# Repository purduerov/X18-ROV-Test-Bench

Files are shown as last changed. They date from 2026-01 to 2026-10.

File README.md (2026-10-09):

# X18 ROV Test Bench

Surface test-bench hardware for the Purdue ROV team (X18 vehicle generation):
carrier and power boards for topside validation without the vehicle in the water.

## Layout

- `MCU and Pi Board/` — MCU + Raspberry Pi carrier board
  (`mcu and pi board.kicad_sch` / `.kicad_pcb`, project-local `Libraries/`,
  `custom library.*`)
- `power/` — power distribution board (`power.kicad_sch` / `.kicad_pcb`,
  `power_symbols.*`, rail sheets such as `12-5`, `48-12`, `STM`)

## Tooling

- Designed in KiCad — open the `.kicad_pro` in each board folder.
- Fab/plot outputs (`outputs/`, `manufacturing/`, Gerbers), KiCad
  auto-backups (`*-backups/`), caches, and component source archives
  (`*.zip`) are git-ignored; regenerate them locally.

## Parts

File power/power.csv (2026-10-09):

Reference | Value | MPN | LCSC | Qty | Footprint | DNP
C19,C27 | 0.1uF | CC0603KRX7R9BB104 | C14663 | 2 | Capacitor_SMD:C_0603_1608Metric
R4 | 73k2 | 0603WAF7322T5E | C14890 | 1 | Resistor_SMD:R_0603_1608Metric
C25,C28,C29 | 1uF | CL10A105KB8NNNC | C15849 | 3 | Capacitor_SMD:C_0603_1608Metric
R12,R13 | 0R | 0603WAF0000T5E | C21189 | 2 | Resistor_SMD:R_0603_1608Metric
R20,R21,R22 | 120R | 0603WAF1200T5E | C22787 | 3 | Resistor_SMD:R_0603_1608Metric
R17 | 15k | 0603WAF1502T5E | C22809 | 1 | Resistor_SMD:R_0603_1608Metric
R14 | 30k | 0603WAF3002T5E | C22984 | 1 | Resistor_SMD:R_0603_1608Metric
R8 | 52k3 | 0603WAF5232T5E | C23198 | 1 | Resistor_SMD:R_0603_1608Metric
R5 | 100k | 0603WAF1003T5E | C25803 | 1 | Resistor_SMD:R_0603_1608Metric
R1,R2,R3,R6,R7,R9,R10,R11,R15,R16 | 10k | 0603WAF1002T5E | C25804 | 10 | Resistor_SMD:R_0603_1608Metric
C13,C14,C15,C16,C17,C18,C23,C24,C30,C31,C33,C34 | 10uF | CL10A106MA8NRNC | C96446 | 12 | Capacitor_SMD:C_0603_1608Metric
C26 | 22nF 1mOhm | CC0603KRX7R9BB223 | C106222 | 1 | Capacitor_SMD:C_0603_1608Metric
C20 | 150pF 0Ohm | CC0603JRNPO9BN151 | C107038 | 1 | Capacitor_SMD:C_0603_1608Metric
C3,C4,C5 | 100uF 63V poly | RXW101M1JBK-0815 | C134638 | 3 | Capacitor_THT:CP_Radial_D8.0mm_P3.50mm
C11,C12 | 2.2mF 16V poly | GR1J222MM300A00CV0 | C240374 | 2 | Capacitor_THT:CP_Radial_D18.0mm_P7.50mm
C1,C2 | 330uF 63V poly | 63YXJ330M12.5X20 | C437640 | 2 | Capacitor_THT:CP_Radial_D12.5mm_P5.00mm
R18,R19,R23,R24,R25 | 680R 1/4W | ERJPA3J681V | C445820 | 5 | Resistor_SMD:R_0603_1608Metric
SW1 | SW_Push | TS04-66-70-BK-160-SMT | C455109 | 1 | power_symbols:TS04-66-70-BK-160-SMT
D2,D5 | RED | XL-1608SURC-06 | C965799 | 2 | LED_SMD:LED_0603_1608Metric
D3,D6 | GREEN | XL-1608UGC-04 | C965804 | 2 | LED_SMD:LED_0603_1608Metric
D1 | BLUE | XL-1608UBC-04 | C965807 | 1 | LED_SMD:LED_0603_1608Metric
C21,C22 | 22uF 2.582mOhm | CL10A226MO7JZNC | C2762594 | 2 | Capacitor_SMD:C_0603_1608Metric
C32 | 3u3 | TCC0603X5R335M250CT | C5360803 | 1 | Capacitor_SMD:C_0603_1608Metric
D4 | PURPLE | XL-1608UVC-04 | C7371898 | 1 | LED_SMD:LED_0603_1608Metric
 |  |  |  |  |  | DNP

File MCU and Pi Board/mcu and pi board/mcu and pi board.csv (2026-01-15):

Reference | Qty | Value | Voltage Rating | Footprint | Datasheet
C1,C5 | 2 | 47u | 10V | Capacitor_SMD:C_0805_2012Metric_Pad1.18x1.45mm_HandSolder | ~
C2,C3,C4,C7,C13,C14,C15,C16,C17,C18,C19 | 11 | 0.1u | 10V | Capacitor_SMD:C_0603_1608Metric_Pad1.08x0.95mm_HandSolder | ~
C6 | 1 | 10u | 10V | Capacitor_SMD:C_0805_2012Metric_Pad1.18x1.45mm_HandSolder | ~
C8,C22,C28,C29,C30,C31,C34,C36,C40 | 9 | 10u | 25V | Capacitor_SMD:C_0805_2012Metric_Pad1.18x1.45mm_HandSolder | ~
C9,C21,C32,C35,C37,C39 | 6 | 0.1u | 25V | Capacitor_SMD:C_0603_1608Metric_Pad1.08x0.95mm_HandSolder | ~
C10 | 1 | 0.47u | 10V | Capacitor_SMD:C_0603_1608Metric_Pad1.08x0.95mm_HandSolder | ~
C11 | 1 | 33u | 10V | Capacitor_SMD:C_0805_2012Metric_Pad1.18x1.45mm_HandSolder | ~
C12 | 1 | 10u | 10V | Capacitor_SMD:C_0603_1608Metric_Pad1.08x0.95mm_HandSolder | ~
C20 | 1 | 3.3n | 25V | Capacitor_SMD:C_0805_2012Metric_Pad1.18x1.45mm_HandSolder | ~
C23 | 1 | 0.1u | 16V | Capacitor_SMD:C_0603_1608Metric_Pad1.08x0.95mm_HandSolder | ~
C24 | 1 | 120p | 50V | Capacitor_SMD:C_0603_1608Metric_Pad1.08x0.95mm_HandSolder | ~
C25 | 1 | 4.7n | 50V | Capacitor_SMD:C_0805_2012Metric_Pad1.18x1.45mm_HandSolder | ~
C26 | 1 | 2.2u | 10V | Capacitor_SMD:C_0603_1608Metric_Pad1.08x0.95mm_HandSolder | ~
C27 | 1 | 1n | 50V | Capacitor_SMD:C_0603_1608Metric_Pad1.08x0.95mm_HandSolder | ~
C33 | 1 | 1u | 25V | Capacitor_SMD:C_0603_1608Metric_Pad1.08x0.95mm_HandSolder | ~
C38 | 1 | 100u | 10V | Capacitor_SMD:C_1206_3216Metric_Pad1.33x1.80mm_HandSolder | ~
D1 | 1 | GREEN_LED |  | LED_SMD:LED_0201_0603Metric_Pad0.64x0.40mm_HandSolder | ~
D2 | 1 | PURPLE_LED |  | LED_SMD:LED_0201_0603Metric_Pad0.64x0.40mm_HandSolder | ~
D3 | 1 | RED_LED |  | LED_SMD:LED_0201_0603Metric_Pad0.64x0.40mm_HandSolder | ~
D4 | 1 | ORANGE_LED |  | LED_SMD:LED_0201_0603Metric_Pad0.64x0.40mm_HandSolder | ~
IC1,IC2 | 2 | CSD17578Q3A |  | custom library:TRANS_CSD18543Q3A
J1 | 1 | BM04B-GHS-TBT |  | custom library:CONN_BM04B-GHS-TBT_JST | BM04B-GHS-TBT
J2 | 1 | ET60S-D04-3-08-D04-X-R1-S |  | custom library:SAMTEC_ET60S-D04-3-08-D04-X-R1-S
J3,J5 | 2 | PJ-002A |  | custom library:CUI_PJ-002A
J4 | 1 | Conn_01x04_Socket |  | Connector_JST:JST_PH_S4B-PH-K_1x04_P2.00mm_Horizontal | ~
J6,J24 | 2 | IPBT-105-H1-T-D-GP |  | custom library:SAMTEC_IPBT-105-H1-T-D-GP
J7 | 1 | Conn_02x04_Counter_Clockwise |  | Connector_PinHeader_2.54mm:PinHeader_2x04_P2.54mm_Vertical | ~
J8,J12,J21 | 3 | Conn_01x02_Pin |  | Connector_PinHeader_2.54mm:PinHeader_1x02_P2.54mm_Vertical | ~
J9 | 1 | Conn_01x05 |  | Connector_PinSocket_2.54mm:PinSocket_1x05_P2.54mm_Vertical | ~
J10 | 1 | 430450428 |  | custom library:MOLEX_430450428
J11,J18,J20 | 3 | Conn_01x04_Pin |  | Connector_PinHeader_2.54mm:PinHeader_1x04_P2.54mm_Vertical | ~
J13,J19,J22 | 3 | Conn_01x03_Pin |  | Connector_PinHeader_2.54mm:PinHeader_1x03_P2.54mm_Vertical | ~
J14 | 1 | ET60T-D04-0-00-D04-X-R1-S |  | custom library:SAMTEC_ET60T-D04-0-00-D04-X-R1-S
J15,J16 | 2 | Conn_01x28_Socket |  | Connector_PinSocket_2.54mm:PinSocket_1x28_P2.54mm_Vertical | ~
J17 | 1 | Conn_01x02_Pin |  | Connector_PinSocket_2.54mm:PinSocket_1x02_P2.54mm_Vertical | ~
J23 | 1 | Conn_02x02_Pin |  | Connector_PinSocket_2.54mm:PinSocket_2x02_P2.54mm_Vertical | ~
J25 | 1 | Conn_02x09_Counter_Clockwise |  | Connector_PinHeader_2.54mm:PinHeader_2x09_P2.54mm_Vertical | ~
J26,J29 | 2 | Conn_01x03_Pin |  | Connector_PinSocket_2.54mm:PinSocket_1x03_P2.54mm_Vertical | ~
J27 | 1 | DebugnBoot |  | Connector_PinHeader_2.54mm:PinHeader_1x04_P2.54mm_Vertical | ~
J28 | 1 | UART-PINS |  | Connector_PinHeader_2.54mm:PinHeader_1x03_P2.54mm_Vertical | ~
J30 | 1 | PWM Connector |  | custom library:PWM, 12V, GND JST Connector
J31 | 1 | ESC ADAPTER - BACKPLANE |  | custom library:ESC Adapter - Backplane
J32,J33,J34 | 3 | TB006-508-03BE |  | custom library:CUI_TB006-508-03BE
L1 | 1 | 1u |  | custom library:IND_XAL6030-102MEC | ~
Q1,Q2 | 2 | BSC010N04LS6ATMA1 |  | custom library:TRANS_BSC010N04LS6ATMA1
R1 | 1 | 290 |  | Resistor_SMD:R_0603_1608Metric_Pad0.98x0.95mm_HandSolder | ~
R2 | 1 | 270 |  | Resistor_SMD:R_0603_1608Metric_Pad0.98x0.95mm_HandSolder | ~
R3 | 1 | 510 |  | Resistor_SMD:R_0603_1608Metric_Pad0.98x0.95mm_HandSolder | ~
R4,R5,R6,R7,R8,R12 | 6 | 10k |  | Resistor_SMD:R_0603_1608Metric_Pad0.98x0.95mm_HandSolder | ~
R9 | 1 | 1.1k |  | Resistor_SMD:R_0603_1608Metric_Pad0.98x0.95mm_HandSolder | ~
R10 | 1 | 2.2k |  | Resistor_SMD:R_0603_1608Metric_Pad0.98x0.95mm_HandSolder | ~
R11 | 1 | 100k |  | Resistor_SMD:R_0603_1608Metric_Pad0.98x0.95mm_HandSolder | ~
R13 | 1 | 5.11k |  | Resistor_SMD:R_0603_1608Metric_Pad0.98x0.95mm_HandSolder | ~
R14 | 1 | 243 |  | Resistor_SMD:R_0603_1608Metric_Pad0.98x0.95mm_HandSolder | ~
R15 | 1 | 100 |  | Resistor_SMD:R_0603_1608Metric_Pad0.98x0.95mm_HandSolder | ~
R16 | 1 | 200 |  | Resistor_SMD:R_0603_1608Metric_Pad0.98x0.95mm_HandSolder | ~
S1 | 1 | TS04-66-70-BK-160-SMT |  | custom library:SW_TS04-66-70-BK-160-SMT
TP1,TP2,TP3,TP4,TP5,TP6,TP7 | 7 | TestPoint |  | TestPoint:TestPoint_Pad_D4.0mm | ~
U1 | 1 | LTC4370CMS_PBF |  | custom library:MSOP-16_MS | https://www.analog.com/media/en/technical-documentation/data-sheets/4370f.pdf
U2 | 1 | LM3940IMPX-3.3/NOPB |  | custom library:MP04A | https://www.ti.com/lit/gpn/lm3940
U3 | 1 | STM32F091CCT6 |  | custom library:LQFP48-7x7mm | https://www.st.com/resource/en/datasheet/stm32f091cc.pdf
U4 | 1 | RASPBERRY_PI_4B_4GB |  | custom library:MODULE_RASPBERRY_PI_4B_4GB
U5,U6 | 2 | MC74HC157ADR2G |  | custom library:SOIC-16_ONS | MC74HC157ADR2G
U7 | 1 | TPS40305DRCR |  | custom library:DRC10_2P4X1P65 | https://www.ti.com/lit/gpn/tps40305

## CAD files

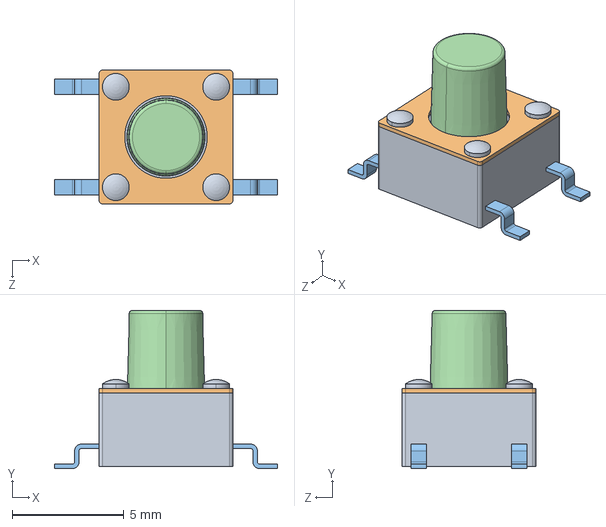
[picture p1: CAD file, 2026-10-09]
power/power_symbols.3d/TS04-66-70-BK-160-SMT.step
10.0 x 7.10 x 6.00 mm

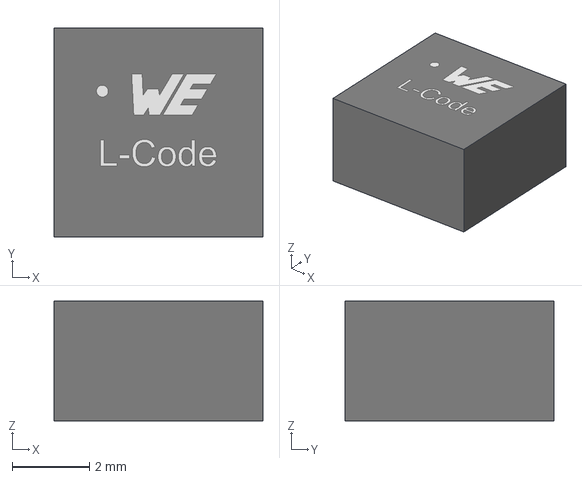
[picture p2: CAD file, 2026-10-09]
power/power_symbols.3d/WE-MXGI_5030.stp
5.40 x 5.40 x 3.10 mm
body_SSMC_5030
land_pattern x 2

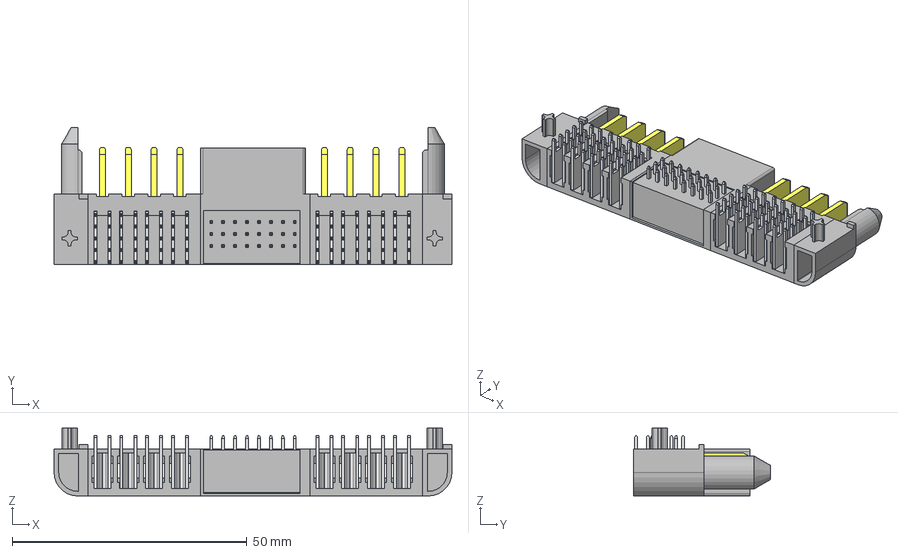
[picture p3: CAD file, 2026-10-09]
power/power_symbols.3d/ET60T-D04-3-08-D04-L-R1-S.stp
84.8 x 29.2 x 14.5 mm
ET60T-24-RT1-GP_st
ET60T-D-04-0-L-_POWER_TERMINAL
ET60T-RT1-GP_gpl
ET60T-D-04-R1-3_POWER_PINS_L_1
ET60T-D-042_POWER_PINS_2
ET60T-D-04-0-R-_POWER_TERMINAL
ET60T-RT1-GP_gpr
ET60T-D-04-R1-_POWER_PINS_R_1
ET60T-D-04-R1-2_POWER_PINS_R_2
ET60T-24-R1-_sp
ET60T-24-R1-2_sp

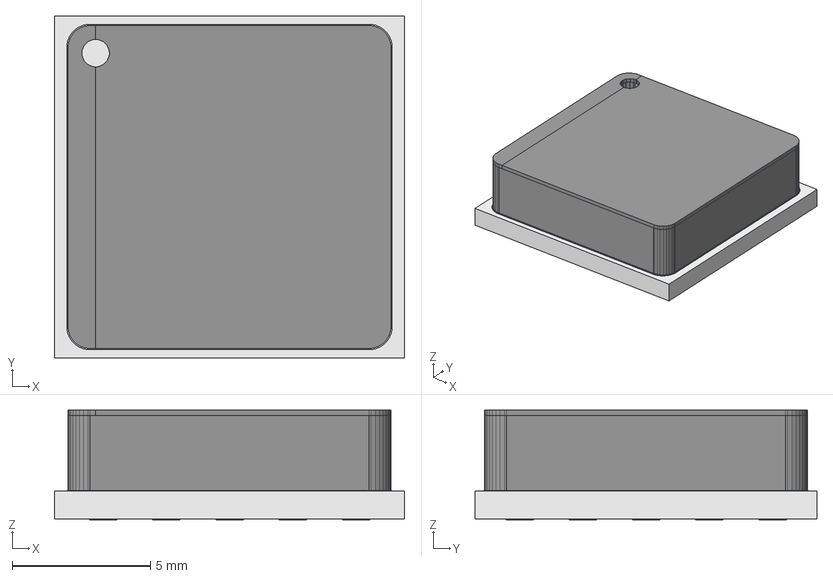
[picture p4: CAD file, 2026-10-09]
power/power_symbols.3d/RPM5.0-6.0.stp
12.7 x 12.4 x 3.97 mm
Extruded.step x 2
Extruded-0.step x 2
Extruded-1.step x 2
Extruded-2.step x 2
Extruded-3.step x 2
Extruded-4.step x 2
Extruded-5.step003 x 4
Extruded-6.step003 x 4
RPM_RBB_PCB028
RPM_RBB_PCB029
RPM_RBB_PCB030
RPM_RBB_PCB031
RPM_RBB_PCB032
RPM_RBB_PCB033
RPM_RBB_PCB034
RPM_RBB_PCB035
RPM_RBB_PCB036
RPM_RBB_PCB037
RPM_RBB_PCB038
RPM_RBB_PCB039
RPM_RBB_PCB040
RPM_RBB_PCB041
RPM_RBB_PCB042
RPM_RBB_PCB043
RPM_RBB_PCB044
RPM_RBB_PCB045
RPM_RBB_PCB046
RPM_RBB_PCB047
RPM_RBB_PCB048
RPM_RBB_PCB049
RPM_RBB_PCB050
RPM_RBB_PCB051
RPM_RBB_PCB052
RPM_RBB_PCB053
RPM_RBB_PCB054
RPM_RBB_PCB
RPM_RBB_PCB001
RPM_RBB_PCB002
RPM_RBB_PCB003
RPM_RBB_PCB004
RPM_RBB_PCB005
RPM_RBB_PCB006
RPM_RBB_PCB007
RPM_RBB_PCB008
RPM_RBB_PCB009
RPM_RBB_PCB010
RPM_RBB_PCB011
RPM_RBB_PCB012
RPM_RBB_PCB013
RPM_RBB_PCB014
RPM_RBB_PCB015
RPM_RBB_PCB016
RPM_RBB_PCB017
RPM_RBB_PCB018
RPM_RBB_PCB019
RPM_RBB_PCB020
RPM_RBB_PCB021
RPM_RBB_PCB022
RPM_RBB_PCB023
RPM_RBB_PCB024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

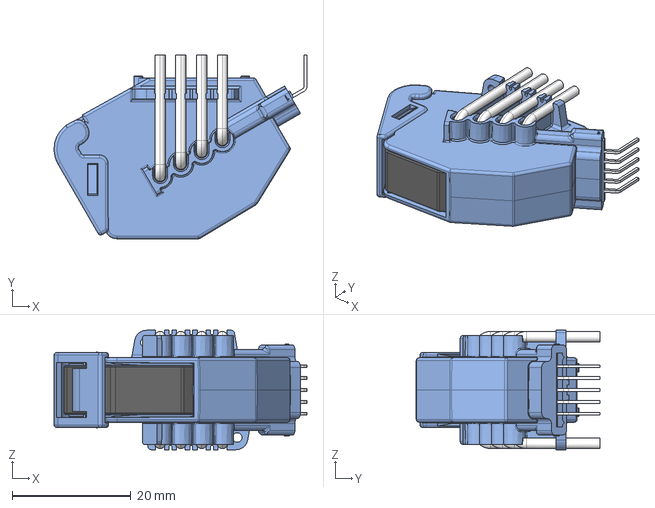
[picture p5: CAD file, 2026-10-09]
power/power_symbols.3d/HO-NP150.stp
42.6 x 30.9 x 20.1 mm

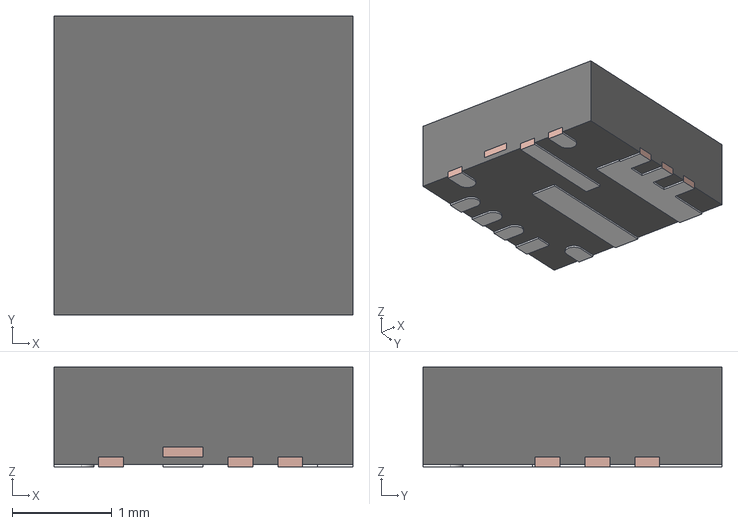
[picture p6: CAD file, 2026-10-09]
power/power_symbols.3d/TPS56A37RPAR.stp
3.00 x 3.00 x 1.00 mm
FRAME
MOLD

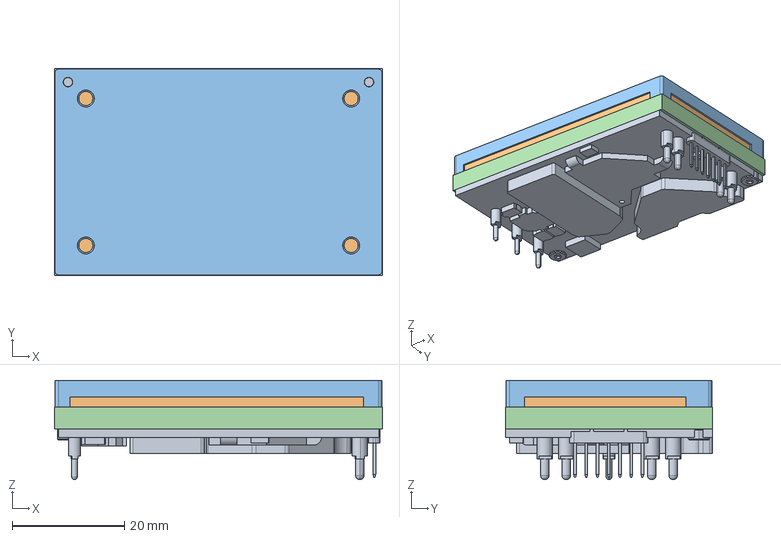
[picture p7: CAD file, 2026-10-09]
power/power_symbols.3d/bmr4912510_871.stp
58.4 x 36.8 x 17.7 mm

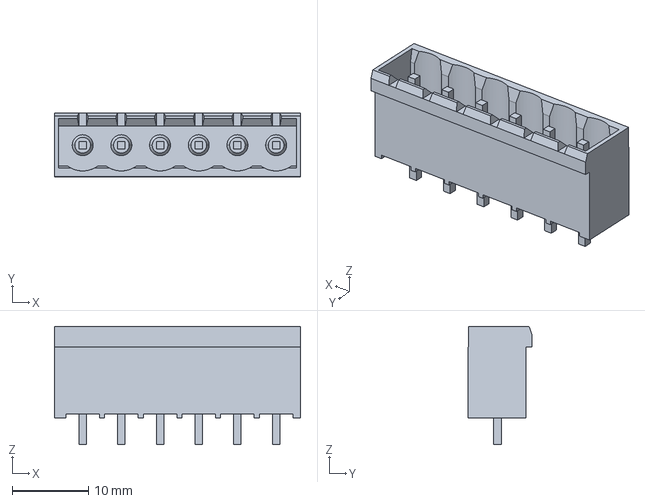
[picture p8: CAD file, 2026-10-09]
power/power_symbols.3d/796636-6.stp
32.3 x 8.35 x 15.5 mm

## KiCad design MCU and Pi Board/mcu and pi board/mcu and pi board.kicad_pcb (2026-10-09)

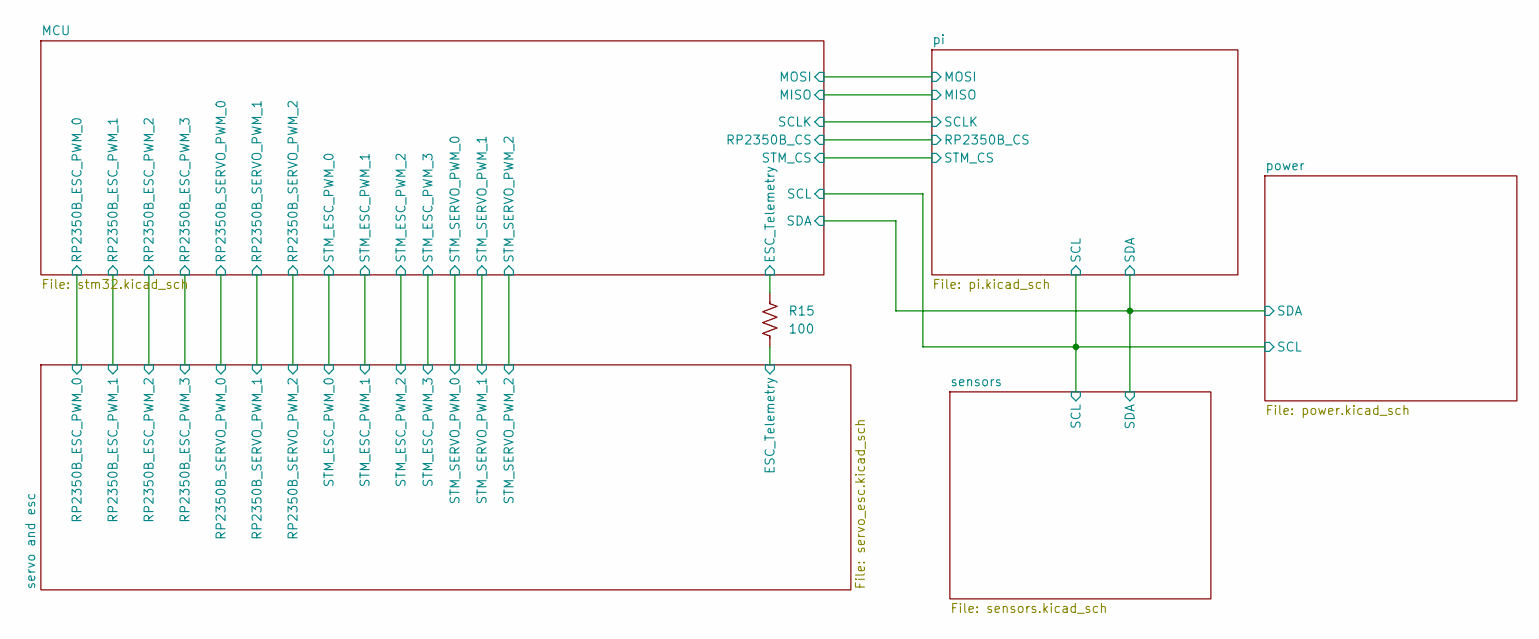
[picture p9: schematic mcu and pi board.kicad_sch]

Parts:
R15: 100; R_0603_1608Metric_Pad0.98x0.95mm_HandSolder

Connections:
/MCU/GPIO13: R15.1; also elsewhere on the board
/servo and esc/ESC_Telemetry: R15.2; also elsewhere on the board

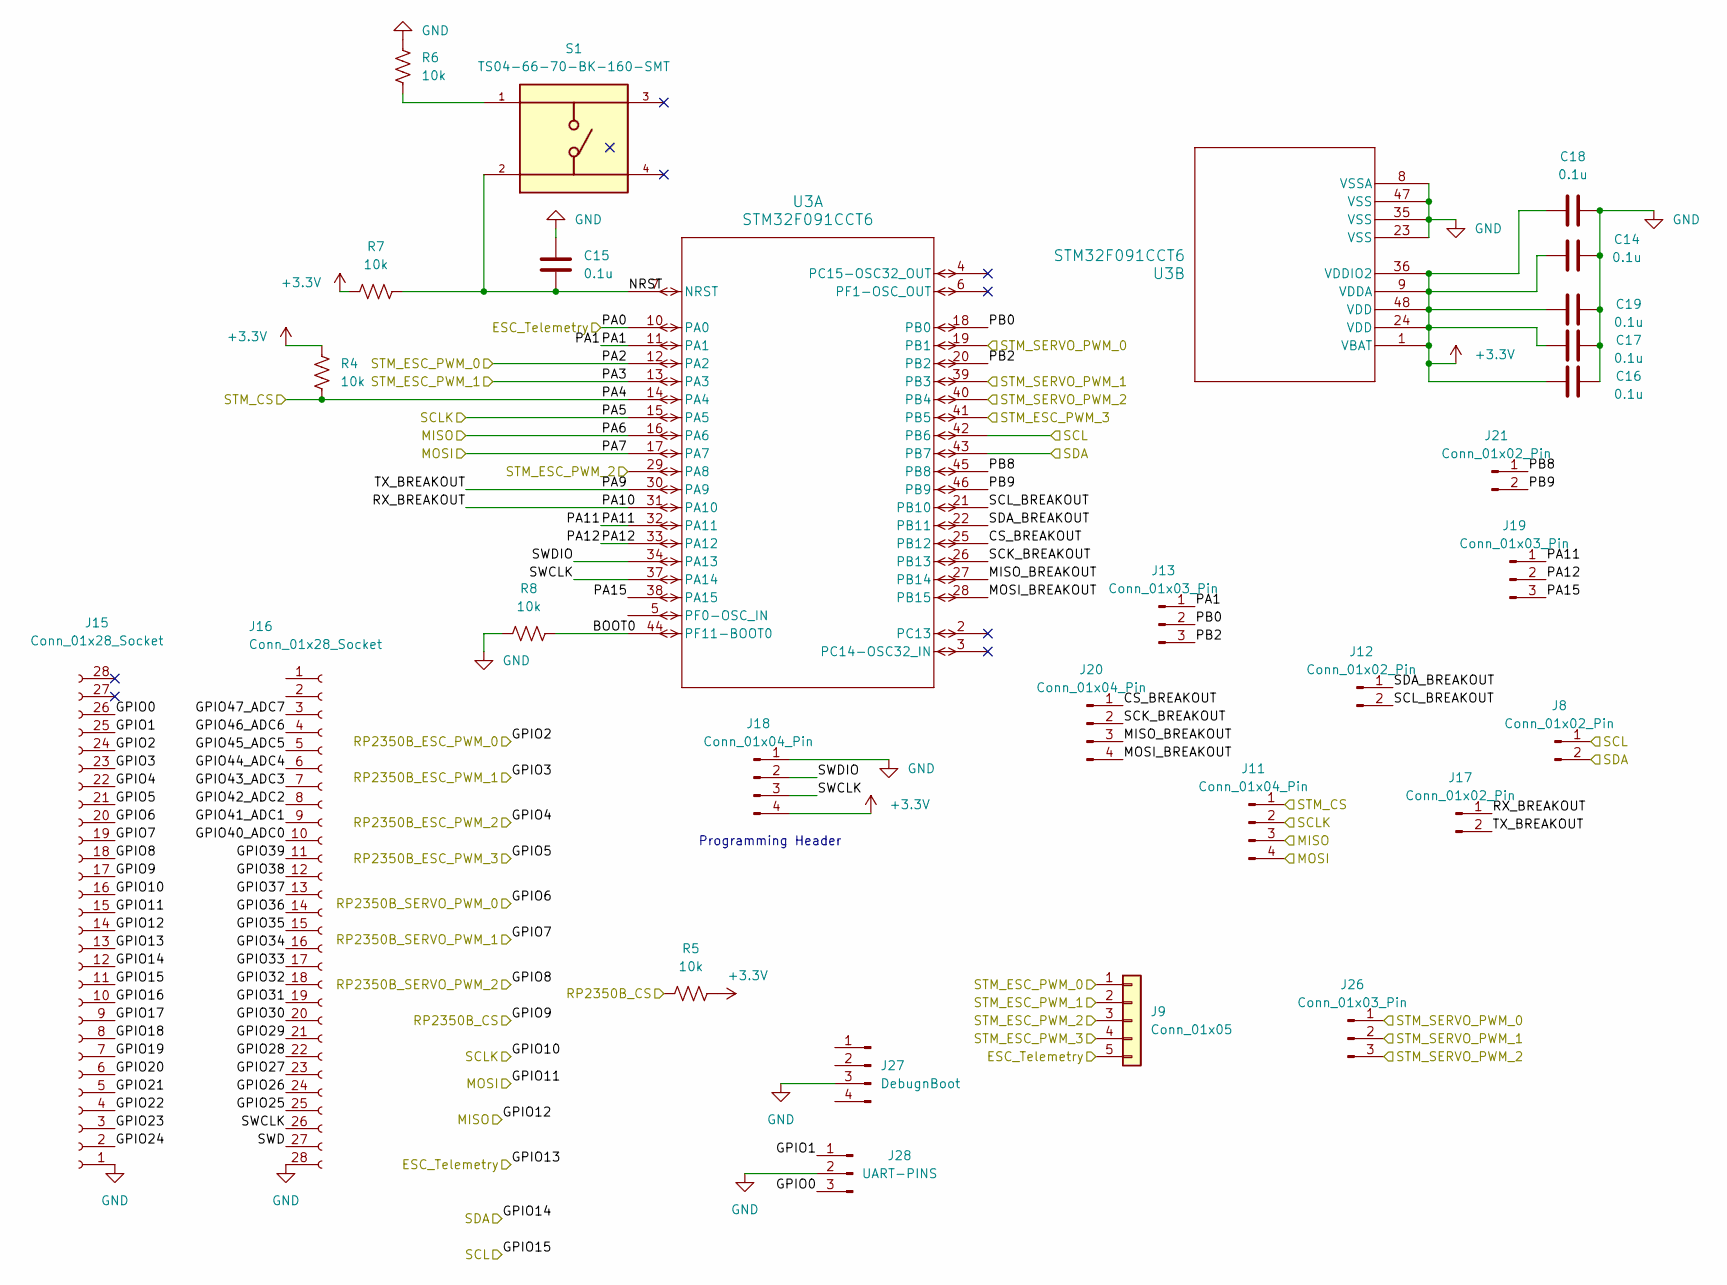
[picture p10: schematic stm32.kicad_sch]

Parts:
C14, C15, C16, C17, C18, C19: 0.1u; C_0603_1608Metric_Pad1.08x0.95mm_HandSolder; Voltage Rating 10V
J8, J12, J21: Conn_01x02_Pin; PinHeader_1x02_P2.54mm_Vertical
J9: Conn_01x05; PinSocket_1x05_P2.54mm_Vertical
J11, J18, J20: Conn_01x04_Pin; PinHeader_1x04_P2.54mm_Vertical
J13, J19: Conn_01x03_Pin; PinHeader_1x03_P2.54mm_Vertical
J15, J16: Conn_01x28_Socket; PinSocket_1x28_P2.54mm_Vertical
J17: Conn_01x02_Pin; PinSocket_1x02_P2.54mm_Vertical
J26: Conn_01x03_Pin; PinSocket_1x03_P2.54mm_Vertical
J27: DebugnBoot; PinHeader_1x04_P2.54mm_Vertical
J28: UART-PINS; PinHeader_1x03_P2.54mm_Vertical
R4, R5, R6, R7, R8: 10k; R_0603_1608Metric_Pad0.98x0.95mm_HandSolder
S1: TS04-66-70-BK-160-SMT; SW_TS04-66-70-BK-160-SMT; PARTREV 1.0
U3: STM32F091CCT6; LQFP48-7x7mm

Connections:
+3.3V: C14.1, C16.1, C17.1, C18.1, C19.1, J18.4, R4.1, R5.2, R7.1, U3.1 (VBAT), U3.9 (VDDA), U3.24 (VDD), U3.36 (VDDIO2), U3.48 (VDD); also elsewhere on the board
/MCU/BOOT0: R8.2, U3.44 (PF11-BOOT0)
/MCU/CS_BREAKOUT: J20.1, U3.25 (PB12)
/MCU/GPIO0: J15.26, J28.3
/MCU/GPIO1: J15.25, J28.1
/MCU/GPIO2: J15.24; also elsewhere on the board
/MCU/GPIO3: J15.23; also elsewhere on the board
/MCU/GPIO4: J15.22; also elsewhere on the board
/MCU/GPIO5: J15.21; also elsewhere on the board
/MCU/GPIO6: J15.20; also elsewhere on the board
/MCU/GPIO7: J15.19; also elsewhere on the board
/MCU/GPIO8: J15.18; also elsewhere on the board
/MCU/GPIO9: J15.17, R5.1; also elsewhere on the board
/MCU/GPIO10: J11.2, J15.16, U3.15 (PA5); also elsewhere on the board
/MCU/GPIO11: J11.4, J15.15, U3.17 (PA7); also elsewhere on the board
/MCU/GPIO12: J11.3, J15.14, U3.16 (PA6); also elsewhere on the board
/MCU/GPIO13: J9.5, J15.13, U3.10 (PA0); also elsewhere on the board
/MCU/GPIO14: J8.2, J15.12, U3.43 (PB7); also elsewhere on the board
/MCU/GPIO15: J8.1, J15.11, U3.42 (PB6); also elsewhere on the board
/MCU/GPIO16: J15.10
/MCU/GPIO17: J15.9
/MCU/GPIO18: J15.8
/MCU/GPIO19: J15.7
/MCU/GPIO20: J15.6
/MCU/GPIO21: J15.5
/MCU/GPIO22: J15.4
/MCU/GPIO23: J15.3
/MCU/GPIO24: J15.2
/MCU/GPIO25: J16.25
/MCU/GPIO26: J16.24
/MCU/GPIO27: J16.23
/MCU/GPIO28: J16.22
/MCU/GPIO29: J16.21
/MCU/GPIO30: J16.20
/MCU/GPIO31: J16.19
/MCU/GPIO32: J16.18
/MCU/GPIO33: J16.17
/MCU/GPIO34: J16.16
/MCU/GPIO35: J16.15
/MCU/GPIO36: J16.14
/MCU/GPIO37: J16.13
/MCU/GPIO38: J16.12
/MCU/GPIO39: J16.11
/MCU/GPIO40_ADC0: J16.10
/MCU/GPIO41_ADC1: J16.9
/MCU/GPIO42_ADC2: J16.8
/MCU/GPIO43_ADC3: J16.7
/MCU/GPIO44_ADC4: J16.6
/MCU/GPIO45_ADC5: J16.5
/MCU/GPIO46_ADC6: J16.4
/MCU/GPIO47_ADC7: J16.3
/MCU/MISO_BREAKOUT: J20.3, U3.27 (PB14)
/MCU/MOSI_BREAKOUT: J20.4, U3.28 (PB15)
/MCU/NRST: C15.2, R7.2, S1.2, U3.7 (NRST)
/MCU/PA1: J13.1, U3.11 (PA1)
/MCU/PA2: J9.1, U3.12 (PA2); also elsewhere on the board
/MCU/PA3: J9.2, U3.13 (PA3); also elsewhere on the board
/MCU/PA4: J11.1, R4.2, U3.14 (PA4); also elsewhere on the board
/MCU/PA9: J17.2, U3.30 (PA9)
/MCU/PA10: J17.1, U3.31 (PA10)
/MCU/PA11: J19.1, U3.32 (PA11)
/MCU/PA12: J19.2, U3.33 (PA12)
/MCU/PA15: J19.3, U3.38 (PA15)
/MCU/PB0: J13.2, U3.18 (PB0)
/MCU/PB2: J13.3, U3.20 (PB2)
/MCU/PB8: J21.1, U3.45 (PB8)
/MCU/PB9: J21.2, U3.46 (PB9)
/MCU/SCK_BREAKOUT: J20.2, U3.26 (PB13)
/MCU/SCL_BREAKOUT: J12.2, U3.21 (PB10)
/MCU/SDA_BREAKOUT: J12.1, U3.22 (PB11)
/MCU/STM_ESC_PWM_2: J9.3, U3.29 (PA8); also elsewhere on the board
/MCU/STM_ESC_PWM_3: J9.4, U3.41 (PB5); also elsewhere on the board
/MCU/STM_SERVO_PWM_0: J26.1, U3.19 (PB1); also elsewhere on the board
/MCU/STM_SERVO_PWM_1: J26.2, U3.39 (PB3); also elsewhere on the board
/MCU/STM_SERVO_PWM_2: J26.3, U3.40 (PB4); also elsewhere on the board
/MCU/SWCLK: J16.26
/MCU/SWCLK: J18.3, U3.37 (PA14)
/MCU/SWD: J16.27
/MCU/SWDIO: J18.2, U3.34 (PA13)
GND: C14.2, C15.1, C16.2, C17.2, C18.2, C19.2, J15.1, J16.28, J18.1, J27.3, J28.2, R6.2, R8.1, U3.8 (VSSA), U3.23 (VSS), U3.35 (VSS), U3.47 (VSS); also elsewhere on the board
unnamed: R6.1, S1.1

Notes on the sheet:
Programming Header

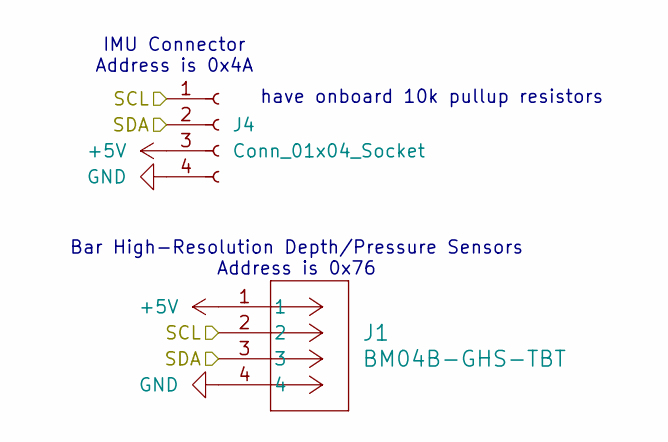
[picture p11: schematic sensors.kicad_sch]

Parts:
J1: BM04B-GHS-TBT; CONN_BM04B-GHS-TBT_JST
J4: Conn_01x04_Socket; JST_PH_S4B-PH-K_1x04_P2.00mm_Horizontal

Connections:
+5V: J1.1, J4.3; also elsewhere on the board
/MCU/GPIO14: J1.3, J4.2; also elsewhere on the board
/MCU/GPIO15: J1.2, J4.1; also elsewhere on the board
GND: J1.4, J4.4; also elsewhere on the board

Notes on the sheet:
Bar High-Resolution Depth/Pressure Sensors Address is 0x76
have onboard 10k pullup resistors
IMU Connector Address is 0x4A

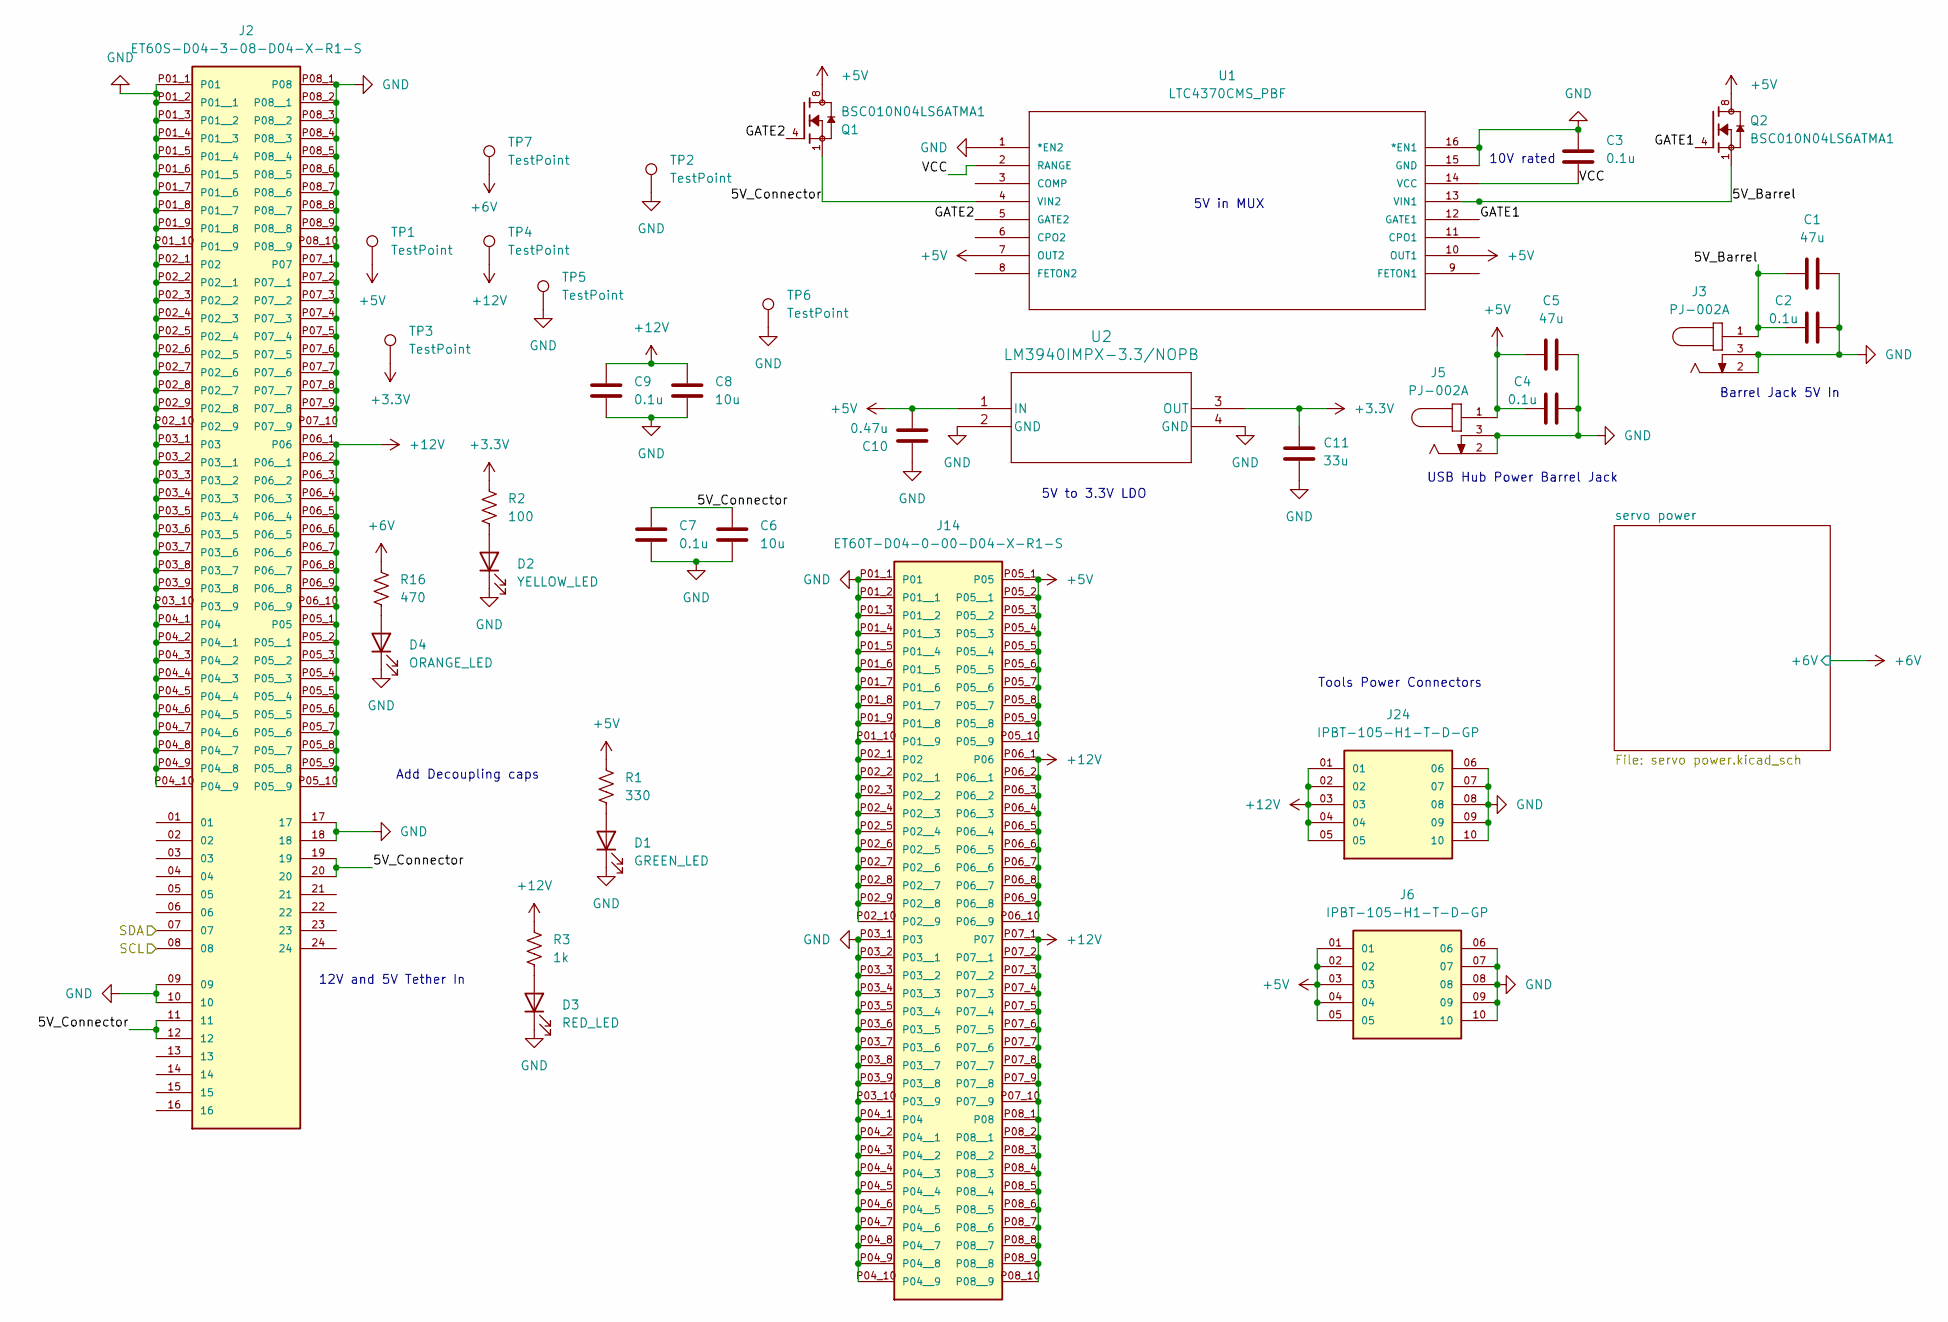
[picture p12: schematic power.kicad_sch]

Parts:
C1, C5: 47u; C_0805_2012Metric_Pad1.18x1.45mm_HandSolder; Voltage Rating 10V
C2, C3, C4, C7: 0.1u; C_0603_1608Metric_Pad1.08x0.95mm_HandSolder; Voltage Rating 10V
C6: 10u; C_0805_2012Metric_Pad1.18x1.45mm_HandSolder; Voltage Rating 10V
C8: 10u; C_0805_2012Metric_Pad1.18x1.45mm_HandSolder; Voltage Rating 25V
C9: 0.1u; C_0603_1608Metric_Pad1.08x0.95mm_HandSolder; Voltage Rating 25V
C10: 0.47u; C_0603_1608Metric_Pad1.08x0.95mm_HandSolder; Voltage Rating 10V
C11: 33u; C_0805_2012Metric_Pad1.18x1.45mm_HandSolder; Voltage Rating 10V
D1: GREEN_LED; LED_0805_2012Metric_Pad1.15x1.40mm_HandSolder
D2: YELLOW_LED; LED_0805_2012Metric_Pad1.15x1.40mm_HandSolder
D3: RED_LED; LED_0603_1608Metric_Pad1.05x0.95mm_HandSolder
D4: ORANGE_LED; LED_0603_1608Metric_Pad1.05x0.95mm_HandSolder
J2: ET60S-D04-3-08-D04-X-R1-S; SAMTEC_ET60S-D04-3-08-D04-X-R1-S; PARTREV G
J3, J5: PJ-002A; CUI_PJ-002A
J6, J24: IPBT-105-H1-T-D-GP; SAMTEC_IPBT-105-H1-T-D-GP; PARTREV R
J14: ET60T-D04-0-00-D04-X-R1-S; SAMTEC_ET60T-D04-0-00-D04-X-R1-S; PARTREV K
Q1, Q2: BSC010N04LS6ATMA1; TRANS_BSC010N04LS6ATMA1
R1: 330; R_0603_1608Metric_Pad0.98x0.95mm_HandSolder
R2: 100; R_0603_1608Metric_Pad0.98x0.95mm_HandSolder
R3: 1k; R_0603_1608Metric_Pad0.98x0.95mm_HandSolder
R16: 470; R_0603_1608Metric_Pad0.98x0.95mm_HandSolder
TP1, TP2, TP3, TP4, TP5, TP6, TP7: TestPoint; TestPoint_Pad_D4.0mm
U1: LTC4370CMS_PBF; MSOP-16_MS; MANUFACTURER_PART_NUMBER ltc4370cms#pbf
U2: LM3940IMPX-3.3/NOPB; MP04A

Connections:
+3.3V: C11.1, R2.1, TP3.1, U2.3 (OUT); also elsewhere on the board
+5V: C4.2, C5.1, C10.2, J5.1, J6.01, J6.02, J6.03, J6.04, J6.05, J14.P05_1 (P05), J14.P05_2 (P05__1), J14.P05_3 (P05__2), J14.P05_4 (P05__3), J14.P05_5 (P05__4), J14.P05_6 (P05__5), J14.P05_7 (P05__6), J14.P05_8 (P05__7), J14.P05_9 (P05__8), J14.P05_10 (P05__9), Q1.8, Q2.8, R1.1, TP1.1, U1.7 (OUT2), U1.10 (OUT1), U2.1 (IN); also elsewhere on the board
+6V: R16.1, TP7.1; also elsewhere on the board
+12V: C8.1, C9.1, J2.P05_1 (P05), J2.P05_2 (P05__1), J2.P05_3 (P05__2), J2.P05_4 (P05__3), J2.P05_5 (P05__4), J2.P05_6 (P05__5), J2.P05_7 (P05__6), J2.P05_8 (P05__7), J2.P05_9 (P05__8), J2.P05_10 (P05__9), J2.P06_1 (P06), J2.P06_2 (P06__1), J2.P06_3 (P06__2), J2.P06_4 (P06__3), J2.P06_5 (P06__4), J2.P06_6 (P06__5), J2.P06_7 (P06__6), J2.P06_8 (P06__7), J2.P06_9 (P06__8), J2.P06_10 (P06__9), J14.P06_1 (P06), J14.P06_2 (P06__1), J14.P06_3 (P06__2), J14.P06_4 (P06__3), J14.P06_5 (P06__4), J14.P06_6 (P06__5), J14.P06_7 (P06__6), J14.P06_8 (P06__7), J14.P06_9 (P06__8), J14.P06_10 (P06__9), J14.P07_1 (P07), J14.P07_2 (P07__1), J14.P07_3 (P07__2), J14.P07_4 (P07__3), J14.P07_5 (P07__4), J14.P07_6 (P07__5), J14.P07_7 (P07__6), J14.P07_8 (P07__7), J14.P07_9 (P07__8), J14.P07_10 (P07__9), J14.P08_1 (P08), J14.P08_2 (P08__1), J14.P08_3 (P08__2), J14.P08_4 (P08__3), J14.P08_5 (P08__4), J14.P08_6 (P08__5), J14.P08_7 (P08__6), J14.P08_8 (P08__7), J14.P08_9 (P08__8), J14.P08_10 (P08__9), J24.01, J24.02, J24.03, J24.04, J24.05, R3.1, TP4.1; also elsewhere on the board
/MCU/GPIO14: J2.07; also elsewhere on the board
/MCU/GPIO15: J2.08; also elsewhere on the board
/power/5V_Barrel: C1.1, C2.2, J3.1, Q2.1, U1.13 (VIN1)
/power/5V_Connector: C6.1, C7.1, J2.11, J2.12, J2.19, J2.20, Q1.1, U1.4 (VIN2)
/power/GATE1: Q2.4, U1.12 (GATE1)
/power/GATE2: Q1.4, U1.5 (GATE2)
/power/VCC: C3.2, U1.2 (RANGE), U1.14 (VCC)
GND: C1.2, C2.1, C3.1, C4.1, C5.2, C6.2, C7.2, C8.2, C9.2, C10.1, C11.2, D1.1 (K), D2.1 (K), D3.1 (K), D4.1 (K), J2.09, J2.10, J2.17, J2.18, J2.P01_1 (P01), J2.P01_2 (P01__1), J2.P01_3 (P01__2), J2.P01_4 (P01__3), J2.P01_5 (P01__4), J2.P01_6 (P01__5), J2.P01_7 (P01__6), J2.P01_8 (P01__7), J2.P01_9 (P01__8), J2.P01_10 (P01__9), J2.P02_1 (P02), J2.P02_2 (P02__1), J2.P02_3 (P02__2), J2.P02_4 (P02__3), J2.P02_5 (P02__4), J2.P02_6 (P02__5), J2.P02_7 (P02__6), J2.P02_8 (P02__7), J2.P02_9 (P02__8), J2.P02_10 (P02__9), J2.P03_1 (P03), J2.P03_2 (P03__1), J2.P03_3 (P03__2), J2.P03_4 (P03__3), J2.P03_5 (P03__4), J2.P03_6 (P03__5), J2.P03_7 (P03__6), J2.P03_8 (P03__7), J2.P03_9 (P03__8), J2.P03_10 (P03__9), J2.P04_1 (P04), J2.P04_2 (P04__1), J2.P04_3 (P04__2), J2.P04_4 (P04__3), J2.P04_5 (P04__4), J2.P04_6 (P04__5), J2.P04_7 (P04__6), J2.P04_8 (P04__7), J2.P04_9 (P04__8), J2.P04_10 (P04__9), J2.P07_1 (P07), J2.P07_2 (P07__1), J2.P07_3 (P07__2), J2.P07_4 (P07__3), J2.P07_5 (P07__4), J2.P07_6 (P07__5), J2.P07_7 (P07__6), J2.P07_8 (P07__7), J2.P07_9 (P07__8), J2.P07_10 (P07__9), J2.P08_1 (P08), J2.P08_2 (P08__1), J2.P08_3 (P08__2), J2.P08_4 (P08__3), J2.P08_5 (P08__4), J2.P08_6 (P08__5), J2.P08_7 (P08__6), J2.P08_8 (P08__7), J2.P08_9 (P08__8), J2.P08_10 (P08__9), J3.2, J3.3, J5.2, J5.3, J6.06, J6.07, J6.08, J6.09, J6.10, J14.P01_1 (P01), J14.P01_2 (P01__1), J14.P01_3 (P01__2), J14.P01_4 (P01__3), J14.P01_5 (P01__4), J14.P01_6 (P01__5), J14.P01_7 (P01__6), J14.P01_8 (P01__7), J14.P01_9 (P01__8), J14.P01_10 (P01__9), J14.P02_1 (P02), J14.P02_2 (P02__1), J14.P02_3 (P02__2), J14.P02_4 (P02__3), J14.P02_5 (P02__4), J14.P02_6 (P02__5), J14.P02_7 (P02__6), J14.P02_8 (P02__7), J14.P02_9 (P02__8), J14.P02_10 (P02__9), J14.P03_1 (P03), J14.P03_2 (P03__1), J14.P03_3 (P03__2), J14.P03_4 (P03__3), J14.P03_5 (P03__4), J14.P03_6 (P03__5), J14.P03_7 (P03__6), J14.P03_8 (P03__7), J14.P03_9 (P03__8), J14.P03_10 (P03__9), J14.P04_1 (P04), J14.P04_2 (P04__1), J14.P04_3 (P04__2), J14.P04_4 (P04__3), J14.P04_5 (P04__4), J14.P04_6 (P04__5), J14.P04_7 (P04__6), J14.P04_8 (P04__7), J14.P04_9 (P04__8), J14.P04_10 (P04__9), J24.06, J24.07, J24.08, J24.09, J24.10, TP2.1, TP5.1, TP6.1, U1.1 (*EN2), U1.15 (GND), U1.16 (*EN1), U2.2 (GND), U2.4 (GND); also elsewhere on the board
unnamed: D1.2 (A), R1.2
unnamed: D2.2 (A), R2.2
unnamed: D3.2 (A), R3.2
unnamed: D4.2 (A), R16.2

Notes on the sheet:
USB Hub Power Barrel Jack
Barrel Jack 5V In
12V and 5V Tether In
10V rated
Tools Power Connectors
Add Decoupling caps
5V to 3.3V LDO
5V in MUX

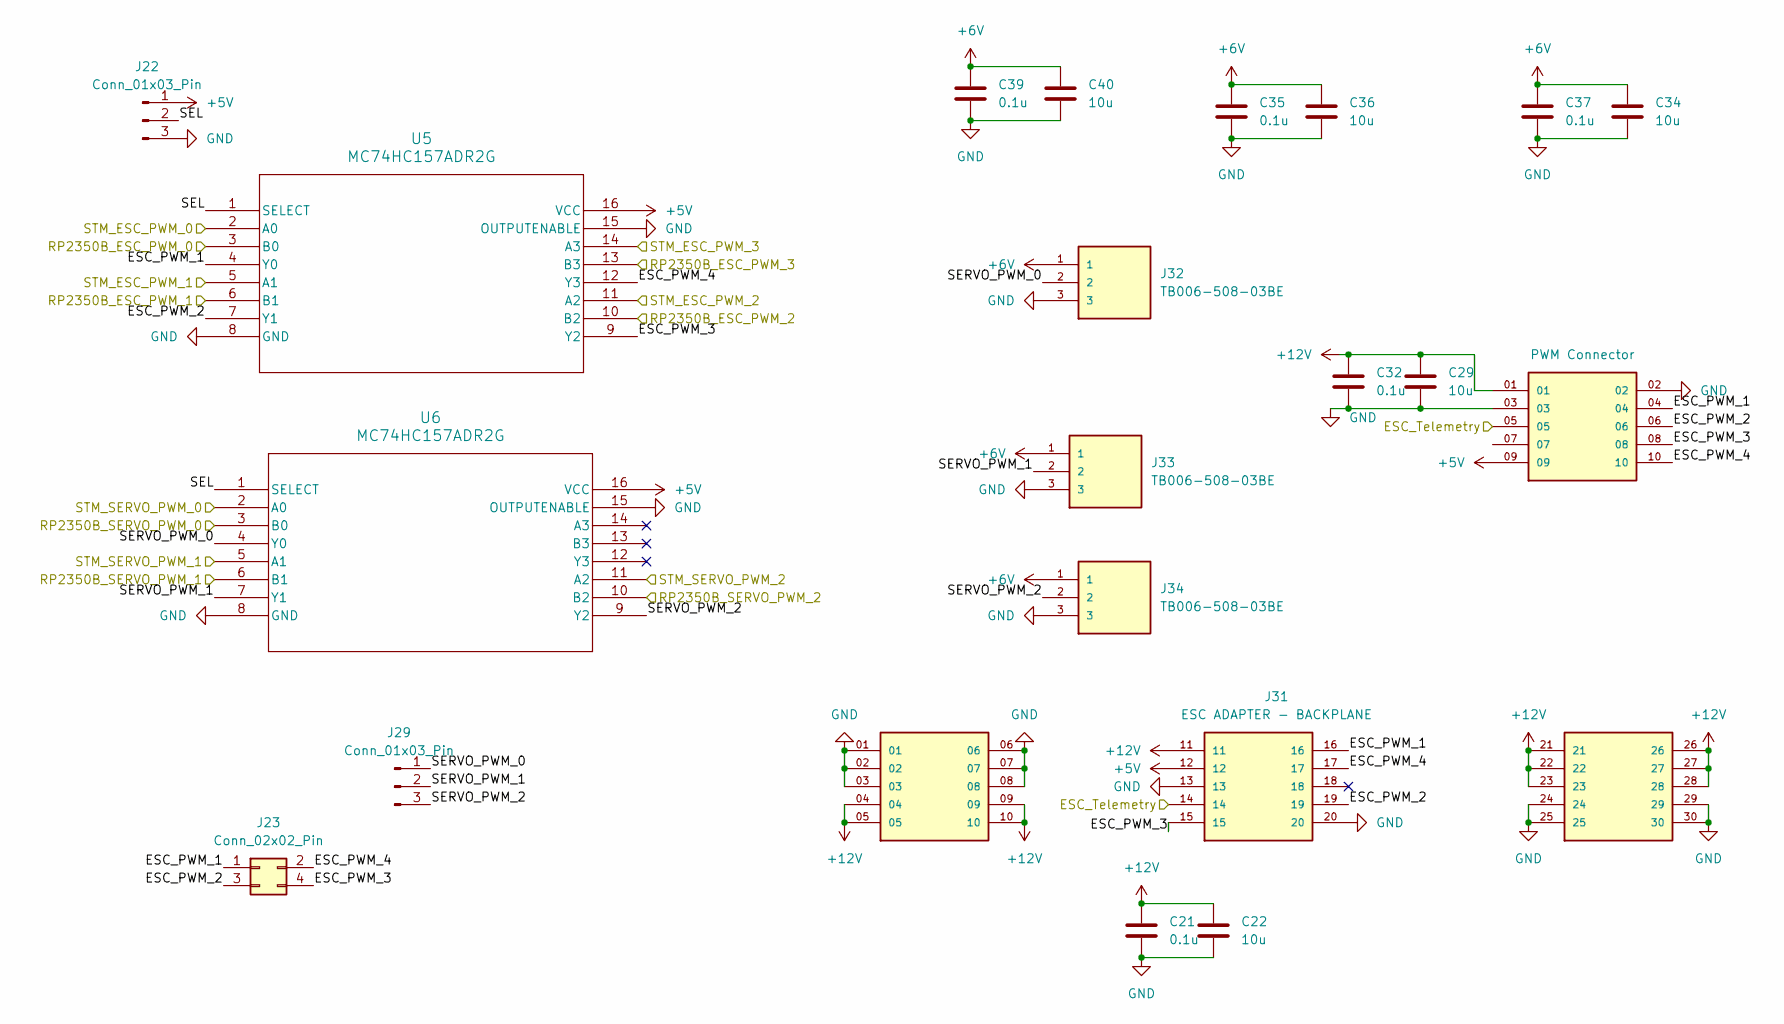
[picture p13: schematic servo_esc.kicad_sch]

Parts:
C21, C32, C35, C37, C39: 0.1u; C_0603_1608Metric_Pad1.08x0.95mm_HandSolder; Voltage Rating 25V
C22, C29, C34, C36, C40: 10u; C_0805_2012Metric_Pad1.18x1.45mm_HandSolder; Voltage Rating 25V
J22: Conn_01x03_Pin; PinHeader_1x03_P2.54mm_Vertical
J23: Conn_02x02_Pin; PinSocket_2x02_P2.54mm_Vertical
J29: Conn_01x03_Pin; PinSocket_1x03_P2.54mm_Vertical
J30: PWM Connector; PWM, 12V, GND JST Connector; PARTREV R
J31: ESC ADAPTER - BACKPLANE; ESC Adapter - Backplane; PARTREV R
J32, J33, J34: TB006-508-03BE; CUI_TB006-508-03BE
U5, U6: MC74HC157ADR2G; SOIC-16_ONS

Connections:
+5V: J22.1, J30.09, J31.12, U5.16 (VCC), U6.16 (VCC); also elsewhere on the board
+6V: C34.1, C35.1, C36.1, C37.1, C39.1, C40.1, J32.1, J33.1, J34.1; also elsewhere on the board
+12V: C21.1, C22.1, C29.1, C32.1, J30.01, J31.04, J31.05, J31.09, J31.10, J31.11, J31.21, J31.22, J31.23, J31.26, J31.27, J31.28; also elsewhere on the board
/MCU/GPIO2: U5.3 (B0); also elsewhere on the board
/MCU/GPIO3: U5.6 (B1); also elsewhere on the board
/MCU/GPIO4: U5.10 (B2); also elsewhere on the board
/MCU/GPIO5: U5.13 (B3); also elsewhere on the board
/MCU/GPIO6: U6.3 (B0); also elsewhere on the board
/MCU/GPIO7: U6.6 (B1); also elsewhere on the board
/MCU/GPIO8: U6.10 (B2); also elsewhere on the board
/MCU/PA2: U5.2 (A0); also elsewhere on the board
/MCU/PA3: U5.5 (A1); also elsewhere on the board
/MCU/STM_ESC_PWM_2: U5.11 (A2); also elsewhere on the board
/MCU/STM_ESC_PWM_3: U5.14 (A3); also elsewhere on the board
/MCU/STM_SERVO_PWM_0: U6.2 (A0); also elsewhere on the board
/MCU/STM_SERVO_PWM_1: U6.5 (A1); also elsewhere on the board
/MCU/STM_SERVO_PWM_2: U6.11 (A2); also elsewhere on the board
/servo and esc/ESC_PWM_1: J23.1, J30.04, J31.16, U5.4 (Y0)
/servo and esc/ESC_PWM_2: J23.3, J30.06, J31.19, U5.7 (Y1)
/servo and esc/ESC_PWM_3: J23.4, J30.08, J31.15, U5.9 (Y2)
/servo and esc/ESC_PWM_4: J23.2, J30.10, J31.17, U5.12 (Y3)
/servo and esc/ESC_Telemetry: J30.05, J31.14; also elsewhere on the board
/servo and esc/SEL: J22.2, U5.1 (SELECT), U6.1 (SELECT)
/servo and esc/SERVO_PWM_0: J29.1, J32.2, U6.4 (Y0)
/servo and esc/SERVO_PWM_1: J29.2, J33.2, U6.7 (Y1)
/servo and esc/SERVO_PWM_2: J29.3, J34.2, U6.9 (Y2)
GND: C21.2, C22.2, C29.2, C32.2, C34.2, C35.2, C36.2, C37.2, C39.2, C40.2, J22.3, J30.02, J30.03, J31.01, J31.02, J31.03, J31.06, J31.07, J31.08, J31.13, J31.20, J31.24, J31.25, J31.29, J31.30, J32.3, J33.3, J34.3, U5.8 (GND), U5.15 (OUTPUTENABLE), U6.8 (GND), U6.15 (OUTPUTENABLE); also elsewhere on the board

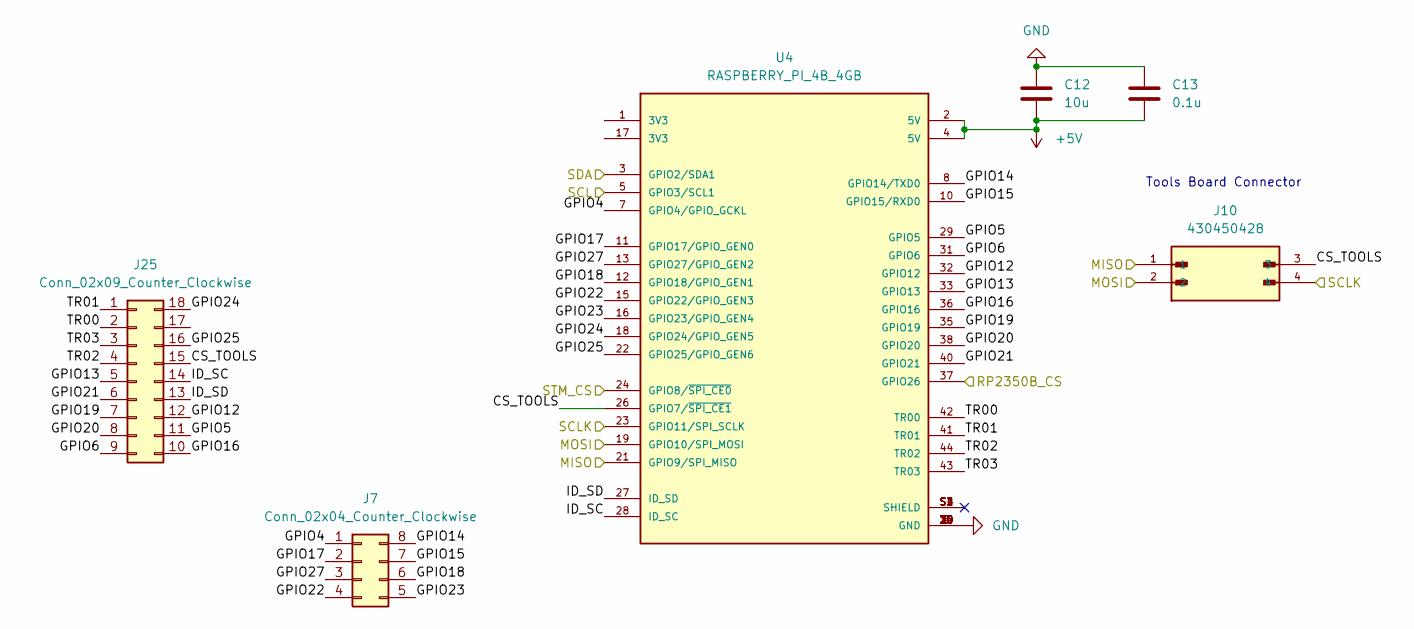
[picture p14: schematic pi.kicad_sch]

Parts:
C12: 10u; C_0603_1608Metric_Pad1.08x0.95mm_HandSolder; Voltage Rating 10V
C13: 0.1u; C_0603_1608Metric_Pad1.08x0.95mm_HandSolder; Voltage Rating 10V
J7: Conn_02x04_Counter_Clockwise; PinHeader_2x04_P2.54mm_Vertical
J10: 430450428; MOLEX_430450428; PARTREV G1
J25: Conn_02x09_Counter_Clockwise; PinHeader_2x09_P2.54mm_Vertical
U4: RASPBERRY_PI_4B_4GB; MODULE_RASPBERRY_PI_4B_4GB; PARTREV 4

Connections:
+5V: C12.2, C13.2, U4.2 (5V), U4.4 (5V); also elsewhere on the board
/MCU/GPIO9: U4.37 (GPIO26); also elsewhere on the board
/MCU/GPIO10: J10.4, U4.23 (GPIO11/SPI_SCLK); also elsewhere on the board
/MCU/GPIO11: J10.2, U4.19 (GPIO10/SPI_MOSI); also elsewhere on the board
/MCU/GPIO12: J10.1, U4.21 (GPIO9/SPI_MISO); also elsewhere on the board
/MCU/GPIO14: U4.3 (GPIO2/SDA1); also elsewhere on the board
/MCU/GPIO15: U4.5 (GPIO3/SCL1); also elsewhere on the board
/MCU/PA4: U4.24 (GPIO8/~SPI_CE0); also elsewhere on the board
/pi/CS_TOOLS: J10.3, J25.15, U4.26 (GPIO7/~SPI_CE1)
/pi/GPIO4: J7.1, U4.7 (GPIO4/GPIO_GCKL)
/pi/GPIO5: J25.11, U4.29 (GPIO5)
/pi/GPIO6: J25.9, U4.31 (GPIO6)
/pi/GPIO12: J25.12, U4.32 (GPIO12)
/pi/GPIO13: J25.5, U4.33 (GPIO13)
/pi/GPIO14: J7.8, U4.8 (GPIO14/TXD0)
/pi/GPIO15: J7.7, U4.10 (GPIO15/RXD0)
/pi/GPIO16: J25.10, U4.36 (GPIO16)
/pi/GPIO17: J7.2, U4.11 (GPIO17/GPIO_GEN0)
/pi/GPIO18: J7.6, U4.12 (GPIO18/GPIO_GEN1)
/pi/GPIO19: J25.7, U4.35 (GPIO19)
/pi/GPIO20: J25.8, U4.38 (GPIO20)
/pi/GPIO21: J25.6, U4.40 (GPIO21)
/pi/GPIO22: J7.4, U4.15 (GPIO22/GPIO_GEN3)
/pi/GPIO23: J7.5, U4.16 (GPIO23/GPIO_GEN4)
/pi/GPIO24: J25.18, U4.18 (GPIO24/GPIO_GEN5)
/pi/GPIO25: J25.16, U4.22 (GPIO25/GPIO_GEN6)
/pi/GPIO27: J7.3, U4.13 (GPIO27/GPIO_GEN2)
/pi/ID_SC: J25.14, U4.28 (ID_SC)
/pi/ID_SD: J25.13, U4.27 (ID_SD)
/pi/TR00: J25.2, U4.42 (TR00)
/pi/TR01: J25.1, U4.41 (TR01)
/pi/TR02: J25.4, U4.44 (TR02)
/pi/TR03: J25.3, U4.43 (TR03)
GND: C12.1, C13.1, U4.6 (GND), U4.9 (GND), U4.14 (GND), U4.20 (GND), U4.25 (GND), U4.30 (GND), U4.34 (GND), U4.39 (GND); also elsewhere on the board

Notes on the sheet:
Tools Board Connector

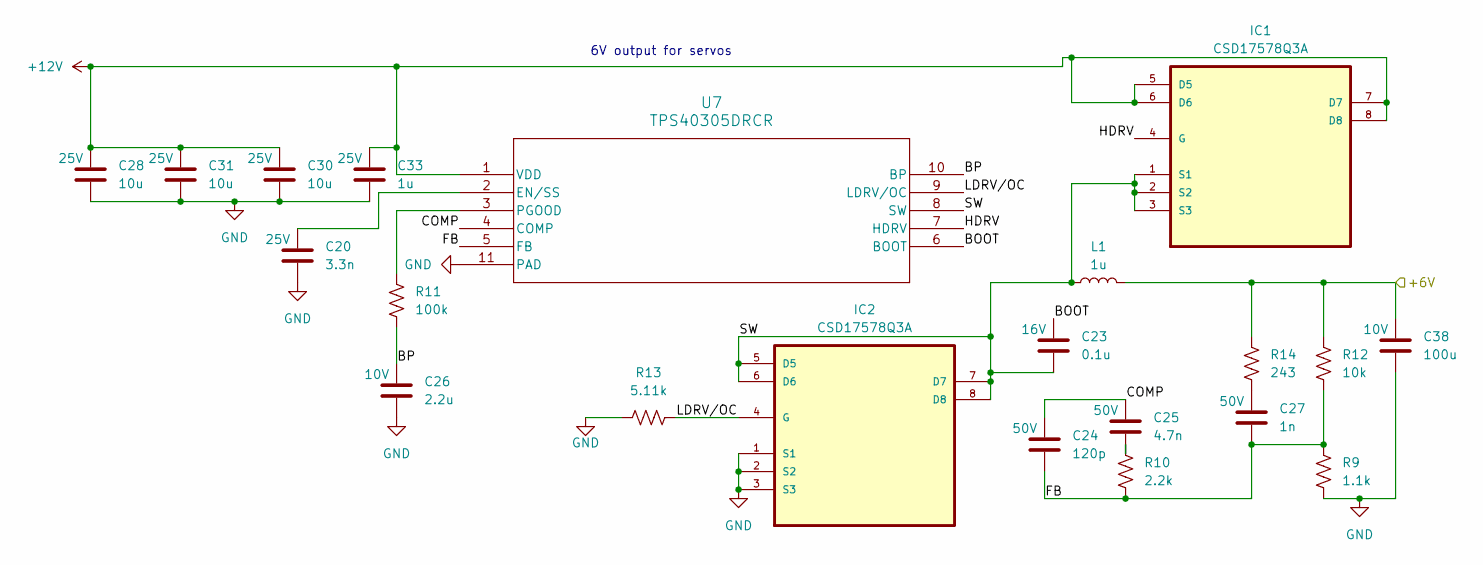
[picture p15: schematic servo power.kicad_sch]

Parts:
C20: 3.3n; C_0805_2012Metric_Pad1.18x1.45mm_HandSolder; Voltage Rating 25V
C23: 0.1u; C_0603_1608Metric_Pad1.08x0.95mm_HandSolder; Voltage Rating 16V
C24: 120p; C_0603_1608Metric_Pad1.08x0.95mm_HandSolder; Voltage Rating 50V
C25: 4.7n; C_0805_2012Metric_Pad1.18x1.45mm_HandSolder; Voltage Rating 50V
C26: 2.2u; C_0603_1608Metric_Pad1.08x0.95mm_HandSolder; Voltage Rating 10V
C27: 1n; C_0603_1608Metric_Pad1.08x0.95mm_HandSolder; Voltage Rating 50V
C28, C30, C31: 10u; C_0805_2012Metric_Pad1.18x1.45mm_HandSolder; Voltage Rating 25V
C33: 1u; C_0603_1608Metric_Pad1.08x0.95mm_HandSolder; Voltage Rating 25V
C38: 100u; C_1206_3216Metric_Pad1.33x1.80mm_HandSolder; Voltage Rating 10V
IC1, IC2: CSD17578Q3A; TRANS_CSD18543Q3A
L1: 1u; IND_XAL6030-102MEC
R9: 1.1k; R_0603_1608Metric_Pad0.98x0.95mm_HandSolder
R10: 2.2k; R_0603_1608Metric_Pad0.98x0.95mm_HandSolder
R11: 100k; R_0603_1608Metric_Pad0.98x0.95mm_HandSolder
R12: 10k; R_0603_1608Metric_Pad0.98x0.95mm_HandSolder
R13: 5.11k; R_0603_1608Metric_Pad0.98x0.95mm_HandSolder
R14: 243; R_0603_1608Metric_Pad0.98x0.95mm_HandSolder
U7: TPS40305DRCR; DRC10_2P4X1P65

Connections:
+6V: C38.1, L1.2, R12.1, R14.1; also elsewhere on the board
+12V: C28.1, C30.1, C31.1, C33.1, IC1.5 (D5), IC1.6 (D6), IC1.7 (D7), IC1.8 (D8), U7.1 (VDD); also elsewhere on the board
/power/servo power/BOOT: C23.1, U7.6 (BOOT)
/power/servo power/BP: C26.1, R11.2, U7.10 (BP)
/power/servo power/COMP: C24.1, C25.1, U7.4 (COMP)
/power/servo power/FB: C24.2, C27.2, R9.1, R10.2, R12.2, U7.5 (FB)
/power/servo power/HDRV: IC1.4 (G), U7.7 (HDRV)
/power/servo power/LDRV/OC: IC2.4 (G), R13.2, U7.9 (LDRV/OC)
/power/servo power/SW: C23.2, IC1.1 (S1), IC1.2 (S2), IC1.3 (S3), IC2.5 (D5), IC2.6 (D6), IC2.7 (D7), IC2.8 (D8), L1.1, U7.8 (SW)
GND: C20.2, C26.2, C28.2, C30.2, C31.2, C33.2, C38.2, IC2.1 (S1), IC2.2 (S2), IC2.3 (S3), R9.2, R13.1, U7.11 (PAD); also elsewhere on the board
unnamed: C25.2, R10.1
unnamed: C27.1, R14.2
unnamed: C20.1, U7.2 (EN/SS)
unnamed: R11.1, U7.3 (PGOOD)

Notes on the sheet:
6V output for servos

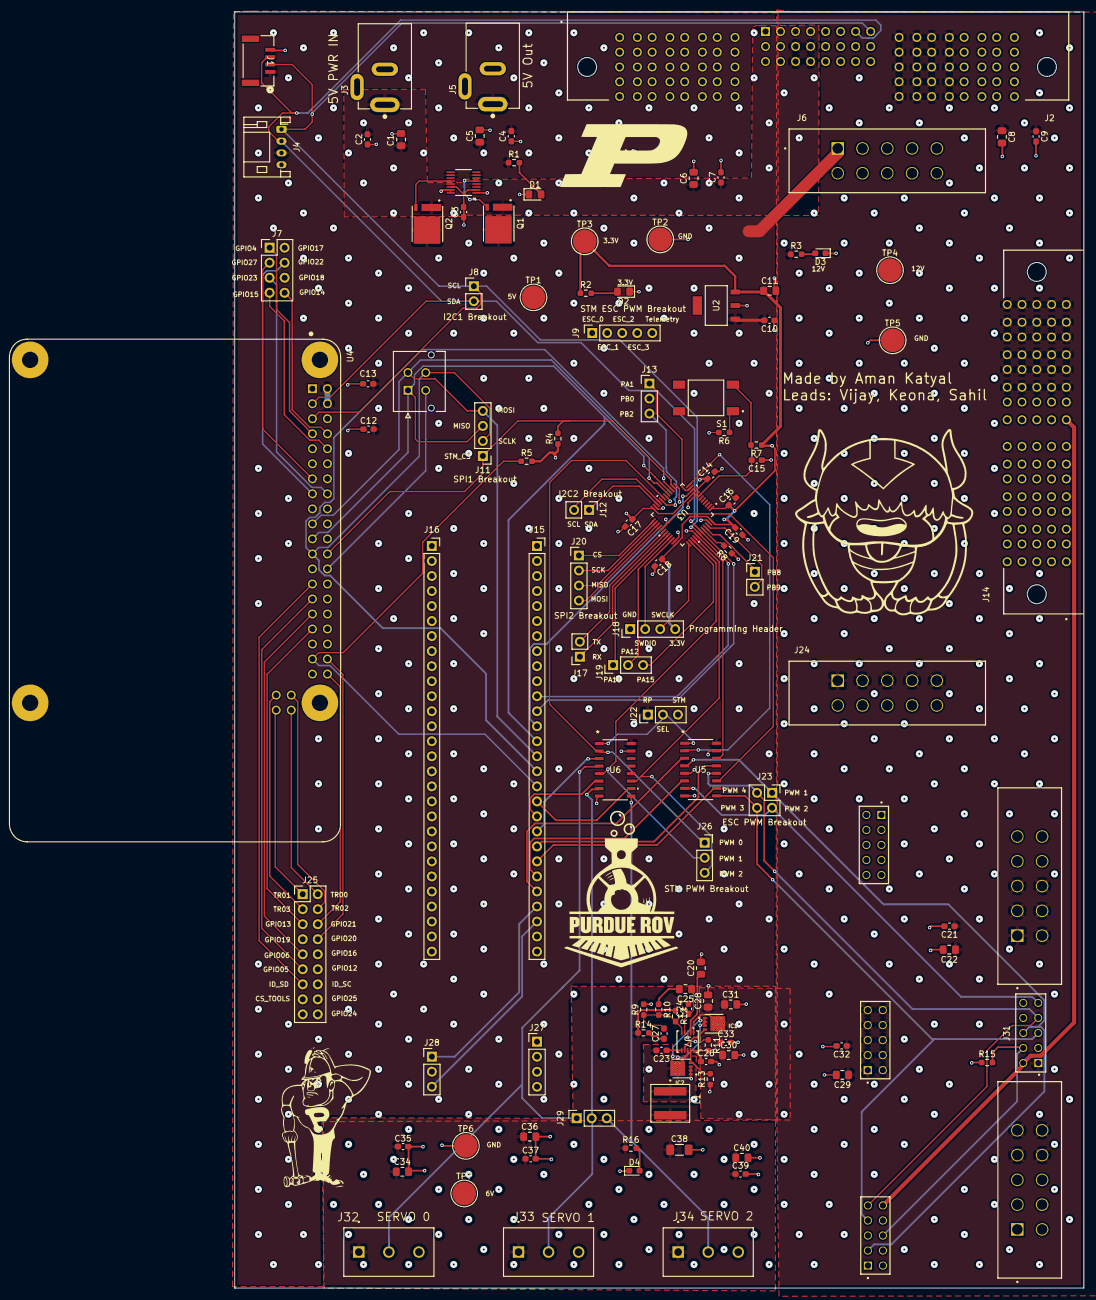
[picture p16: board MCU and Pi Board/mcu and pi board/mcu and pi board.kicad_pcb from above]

Board: 4 copper layers, 143.6 x 215.8 mm, 114 parts (0 on the bottom side), 104 nets.

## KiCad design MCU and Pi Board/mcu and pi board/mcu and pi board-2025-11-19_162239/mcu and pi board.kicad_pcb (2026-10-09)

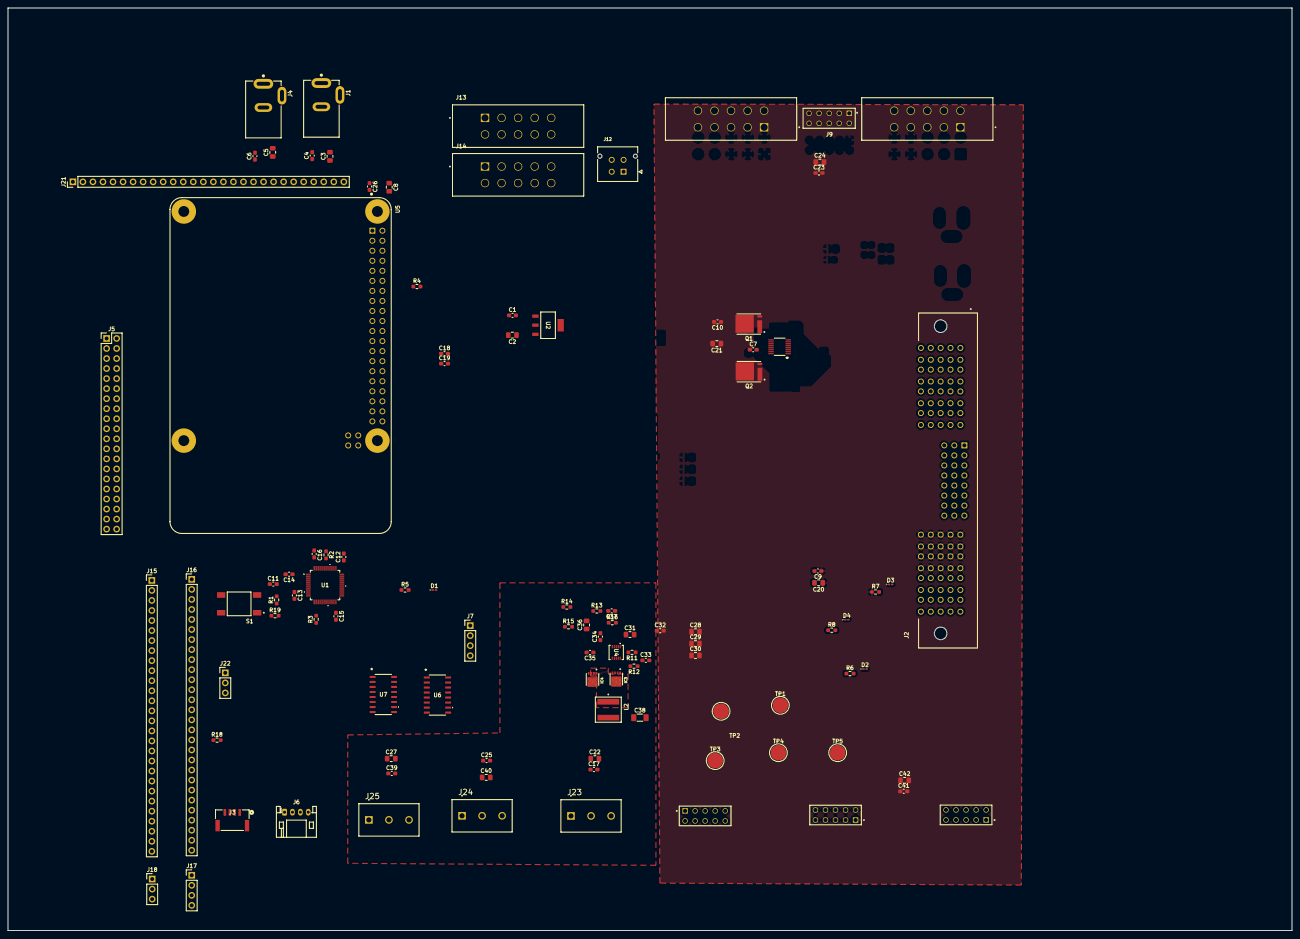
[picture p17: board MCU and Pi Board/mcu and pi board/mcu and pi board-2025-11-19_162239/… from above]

Board: 4 copper layers, 325.0 x 233.5 mm, 101 parts (0 on the bottom side), 110 nets, no tracks yet.

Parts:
C1: 0.47u; C_0603_1608Metric_Pad1.08x0.95mm_HandSolder
C2: 33u; C_0805_2012Metric_Pad1.18x1.45mm_HandSolder
C3, C5: 47u; C_0805_2012Metric_Pad1.18x1.45mm_HandSolder
C4, C6, C7, C9, C10, C11, C12, C13, C14, C15, C16, C17, C18, C19, C23, C25, C26, C35, C39, C41: 0.1u; C_0603_1608Metric_Pad1.08x0.95mm_HandSolder
C8, C20, C21, C22, C24, C27, C28, C29, C30, C40, C42: 10u; C_0805_2012Metric_Pad1.18x1.45mm_HandSolder
C31: 3.3n; C_0805_2012Metric_Pad1.18x1.45mm_HandSolder
C32: 1u; C_0603_1608Metric_Pad1.08x0.95mm_HandSolder
C33: 2.2u; C_0603_1608Metric_Pad1.08x0.95mm_HandSolder
C34: 120p; C_0603_1608Metric_Pad1.08x0.95mm_HandSolder
C36: 4.7n; C_0805_2012Metric_Pad1.18x1.45mm_HandSolder
C37: 1n; C_0603_1608Metric_Pad1.08x0.95mm_HandSolder
C38: 100u; C_1206_3216Metric_Pad1.33x1.80mm_HandSolder
D1: PURPLE_LED; LED_0201_0603Metric_Pad0.64x0.40mm_HandSolder
D2: ORANGE_LED; LED_0201_0603Metric_Pad0.64x0.40mm_HandSolder
D3: RED_LED; LED_0201_0603Metric_Pad0.64x0.40mm_HandSolder
D4: GREEN_LED; LED_0201_0603Metric_Pad0.64x0.40mm_HandSolder
IC3, IC4: CSD17578Q3A; TRANS_CSD18543Q3A
J1, J4: PJ-002A; CUI_PJ-002A
J2: ET60S-D04-3-08-D04-X-R1-S; SAMTEC_ET60S-D04-3-08-D04-X-R1-S
J3: BM04B-GHS-TBT; CONN_BM04B-GHS-TBT_JST
J5: Conn_02x20_Odd_Even; PinHeader_2x20_P2.54mm_Vertical
J6: Conn_01x04_Socket; JST_PH_S4B-PH-K_1x04_P2.00mm_Horizontal
J7: Conn_01x04_Pin; PinHeader_1x04_P2.54mm_Vertical
J8: PWM Connector; PWM, 12V, GND JST Connector
J9: ESC ADAPTER - BACKPLANE; ESC Adapter - Backplane
J12: 430450428; MOLEX_430450428
J13, J14: IPBT-105-H1-T-D-GP; SAMTEC_IPBT-105-H1-T-D-GP
J15, J16, J21: Conn_01x28_Socket; PinHeader_1x28_P2.54mm_Vertical
J17: DebugnBoot; PinHeader_1x04_P2.54mm_Vertical
J18: UART-PINS; PinHeader_1x03_P2.54mm_Vertical
J22: Conn_01x03_Pin; PinHeader_1x03_P2.54mm_Vertical
J23, J24, J25: TB006-508-03BE; CUI_TB006-508-03BE
L2: 1u; IND_XAL6030-102MEC
Q1, Q2: BSC010N04LS6ATMA1; TRANS_BSC010N04LS6ATMA1
R1, R2, R3, R15, R18, R19: 10k; R_0603_1608Metric_Pad0.98x0.95mm_HandSolder
R4: 100; R_0603_1608Metric_Pad0.98x0.95mm_HandSolder
R5: 270; R_0603_1608Metric_Pad0.98x0.95mm_HandSolder
R6: 200; R_0603_1608Metric_Pad0.98x0.95mm_HandSolder
R7: 510; R_0603_1608Metric_Pad0.98x0.95mm_HandSolder
R8: 290; R_0603_1608Metric_Pad0.98x0.95mm_HandSolder
R11: 100k; R_0603_1608Metric_Pad0.98x0.95mm_HandSolder
R12: 5.11k; R_0603_1608Metric_Pad0.98x0.95mm_HandSolder
R13: 2.2k; R_0603_1608Metric_Pad0.98x0.95mm_HandSolder
R14: 243; R_0603_1608Metric_Pad0.98x0.95mm_HandSolder
R16: 1.1k; R_0603_1608Metric_Pad0.98x0.95mm_HandSolder
S1: TS04-66-70-BK-160-SMT; SW_TS04-66-70-BK-160-SMT
TP1, TP2, TP3, TP4, TP5: TestPoint; TestPoint_Pad_D4.0mm
U1: STM32F091CCT6; LQFP48-7x7mm
U2: LM3940IMPX-3.3/NOPB; MP04A
U3: LTC4370CMS_PBF; MSOP-16_MS
U4: TPS40305DRCR; DRC10_2P4X1P65
U5: RASPBERRY_PI_4B_4GB; MODULE_RASPBERRY_PI_4B_4GB
U6, U7: MC74HC157ADR2G; SOIC-16_ONS

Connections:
+3.3V: C2.1, C12.1, C13.1, C14.1, C15.1, C16.1, J6.3, J7.4, R1.1, R3.1, R5.1, R18.2, TP4.1, U1.1 (VBAT), U1.9 (VDDA), U1.24 (VDD), U1.36 (VDDIO2), U1.48 (VDD), U2.3 (OUT)
+5V: C1.2, C5.1, C6.2, C10.1, C18.2, C19.2, C21.1, J3.1, J4.1, J8.09, J9.12, J14.01, J14.02, J14.03, J14.04, J14.05, J22.1, Q1.8, Q2.8, R8.1, TP1.1, U2.1 (IN), U3.7 (OUT2), U3.10 (OUT1), U5.2 (5V), U5.4 (5V), U6.16 (VCC), U7.16 (VCC)
+6V: C17.1, C22.1, C25.1, C27.1, C38.1, C39.1, C40.1, J23.1, J24.1, J25.1, L2.2, R6.1, R14.1, R15.1, TP2.1
+12V: C8.1, C9.1, C20.1, C23.1, C24.1, C26.1, C28.1, C29.1, C30.1, C32.1, C41.1, C42.1, IC4.5 (D5), IC4.6 (D6), IC4.7 (D7), IC4.8 (D8), J2.P05_1 (P05), J2.P05_2 (P05__1), J2.P05_3 (P05__2), J2.P05_4 (P05__3), J2.P05_5 (P05__4), J2.P05_6 (P05__5), J2.P05_7 (P05__6), J2.P05_8 (P05__7), J2.P05_9 (P05__8), J2.P05_10 (P05__9), J2.P06_1 (P06), J2.P06_2 (P06__1), J2.P06_3 (P06__2), J2.P06_4 (P06__3), J2.P06_5 (P06__4), J2.P06_6 (P06__5), J2.P06_7 (P06__6), J2.P06_8 (P06__7), J2.P06_9 (P06__8), J2.P06_10 (P06__9), J8.01, J9.04, J9.05, J9.09, J9.10, J9.11, J9.21, J9.22, J9.23, J9.26, J9.27, J9.28, J13.01, J13.02, J13.03, J13.04, J13.05, R7.1, TP3.1, U4.1 (VDD)
/MCU/BOOT0: J5.2, R2.2, U1.44 (PF11-BOOT0)
/MCU/GPIO0: J16.26, J18.3
/MCU/GPIO1: J16.25, J18.1
/MCU/GPIO2: J16.24, U6.3 (B0)
/MCU/GPIO3: J16.23, U6.6 (B1)
/MCU/GPIO4: J16.22, U6.10 (B2)
/MCU/GPIO5: J16.21, U6.13 (B3)
/MCU/GPIO6: J16.20, U7.3 (B0)
/MCU/GPIO7: J16.19, U7.6 (B1)
/MCU/GPIO8: J16.18, U7.10 (B2)
/MCU/GPIO9: J16.17, R18.1, U5.37 (GPIO26)
/MCU/GPIO10: J5.15, J12.4, J16.16, U1.15 (PA5), U5.23 (GPIO11/SPI_SCLK)
/MCU/GPIO11: J5.19, J12.2, J16.15, U1.17 (PA7), U5.19 (GPIO10/SPI_MOSI)
/MCU/GPIO12: J5.17, J12.1, J16.14, U1.16 (PA6), U5.21 (GPIO9/SPI_MISO)
/MCU/GPIO13: J5.20, J16.13, R4.1, U1.43 (PB7)
/MCU/GPIO14: J2.07, J3.3, J5.24, J6.2, J16.12, U1.46 (PB9), U5.3 (GPIO2/SDA1)
/MCU/GPIO15: J2.08, J3.2, J5.18, J6.1, J16.11, U1.42 (PB6), U5.5 (GPIO3/SCL1)
/MCU/NRST: C11.2, J5.1, R1.2, S1.2, U1.7 (NRST)
/MCU/OSC_IN: J5.37, U1.5 (PF0-OSC_IN)
/MCU/PA0: J5.5, U1.10 (PA0), U6.2 (A0)
/MCU/PA1: J5.7, U1.11 (PA1), U6.5 (A1)
/MCU/PA2: J5.9, U1.12 (PA2), U6.11 (A2)
/MCU/PA3: J5.11, U1.13 (PA3), U6.14 (A3)
/MCU/PA4: J5.13, R3.2, U1.14 (PA4), U5.24 (GPIO8/~SPI_CE0)
/MCU/PA8: J5.21, U1.29 (PA8), U7.2 (A0)
/MCU/PA9: J5.23, U1.30 (PA9), U7.5 (A1)
/MCU/PA10: J5.25, U1.31 (PA10), U7.11 (A2)
/MCU/PA11: J5.27, U1.32 (PA11)
/MCU/PA12: J5.29, U1.33 (PA12)
/MCU/PA15: J5.31, U1.38 (PA15)
/MCU/PB0: J5.6, U1.18 (PB0)
/MCU/PB1: J5.8, U1.19 (PB1)
/MCU/PB2: J5.10, U1.20 (PB2)
/MCU/PB3: J5.12, U1.39 (PB3)
/MCU/PB4: J5.14, U1.40 (PB4)
/MCU/PB5: J5.16, U1.41 (PB5)
/MCU/PB8: J5.22, U1.45 (PB8)
/MCU/PB10: J5.26, U1.21 (PB10)
/MCU/PB11: J5.28, U1.22 (PB11)
/MCU/PB12: J5.30, U1.25 (PB12)
/MCU/PB13: J5.32, U1.26 (PB13)
/MCU/PB14: J5.34, U1.27 (PB14)
/MCU/PB15: J5.36, U1.28 (PB15)
/MCU/PC13: J5.38, U1.2 (PC13)
/MCU/PC14: J5.40, U1.3 (PC14-OSC32_IN)
/MCU/PC15: J5.35, U1.4 (PC15-OSC32_OUT)
/MCU/PF1: J5.33, U1.6 (PF1-OSC_OUT)
/MCU/SWCLK: J5.4, J7.3, U1.37 (PA14)
/MCU/SWDIO: J5.3, J7.2, U1.34 (PA13)
/pi/CS_TOOLS: J12.3, J21.4, U5.26 (GPIO7/~SPI_CE1)
/pi/GPIO4: J21.26, U5.7 (GPIO4/GPIO_GCKL)
/pi/GPIO5: J21.14, U5.29 (GPIO5)
/pi/GPIO6: J21.13, U5.31 (GPIO6)
/pi/GPIO12: J21.12, U5.32 (GPIO12)
/pi/GPIO13: J21.11, U5.33 (GPIO13)
/pi/GPIO14: J21.6, U5.8 (GPIO14/TXD0)
/pi/GPIO15: J21.5, U5.10 (GPIO15/RXD0)
/pi/GPIO16: J21.10, U5.36 (GPIO16)
/pi/GPIO17: J21.25, U5.11 (GPIO17/GPIO_GEN0)
/pi/GPIO18: J21.23, U5.12 (GPIO18/GPIO_GEN1)
/pi/GPIO19: J21.9, U5.35 (GPIO19)
/pi/GPIO20: J21.8, U5.38 (GPIO20)
/pi/GPIO21: J21.7, U5.40 (GPIO21)
/pi/GPIO22: J21.22, U5.15 (GPIO22/GPIO_GEN3)
/pi/GPIO23: J21.21, U5.16 (GPIO23/GPIO_GEN4)
/pi/GPIO24: J21.20, U5.18 (GPIO24/GPIO_GEN5)
/pi/GPIO25: J21.19, U5.22 (GPIO25/GPIO_GEN6)
/pi/GPIO27: J21.24, U5.13 (GPIO27/GPIO_GEN2)
/pi/ID_SC: J21.27, U5.28 (ID_SC)
/pi/ID_SD: J21.28, U5.27 (ID_SD)
/pi/TR00: J21.18, U5.42 (TR00)
/pi/TR01: J21.17, U5.41 (TR01)
/pi/TR02: J21.16, U5.44 (TR02)
/pi/TR03: J21.15, U5.43 (TR03)
/power/5V_Barrel: C3.1, C4.2, J1.1, Q1.1, U3.13 (VIN1)
/power/5V_Connector: J2.11, J2.12, J2.19, J2.20, Q2.1, U3.4 (VIN2)
/power/GATE1: Q1.4, U3.12 (GATE1)
/power/GATE2: Q2.4, U3.5 (GATE2)
/power/VCC: C7.2, U3.2 (RANGE), U3.14 (VCC)
/power/servo power/BOOT: C35.1, U4.6 (BOOT)
/power/servo power/BP: C33.1, R11.2, U4.10 (BP)
/power/servo power/COMP: C34.1, C36.1, U4.4 (COMP)
/power/servo power/FB: C34.2, C37.2, R13.2, R15.2, R16.1, U4.5 (FB)
/power/servo power/HDRV: IC4.4 (G), U4.7 (HDRV)
/power/servo power/LDRV/OC: IC3.4 (G), R12.2, U4.9 (LDRV/OC)
/power/servo power/SW: C35.2, IC3.5 (D5), IC3.6 (D6), IC3.7 (D7), IC3.8 (D8), IC4.1 (S1), IC4.2 (S2), IC4.3 (S3), L2.1, U4.8 (SW)
/servo and esc/ESC_PWM_1: J8.04, J9.16, U6.7 (Y1)
/servo and esc/ESC_PWM_2: J8.06, J9.19, U6.9 (Y2)
/servo and esc/ESC_PWM_3: J8.08, J9.15, U6.12 (Y3)
/servo and esc/ESC_PWM_4: J8.10, J9.17
/servo and esc/ESC_Telemetry: J8.05, J9.14, R4.2
/servo and esc/SEL: J22.2, U6.1 (SELECT), U7.1 (SELECT)
/servo and esc/SERVO_PWM_0: J23.2, U7.4 (Y0)
/servo and esc/SERVO_PWM_1: J24.2, U7.7 (Y1)
/servo and esc/SERVO_PWM_2: J25.2, U7.9 (Y2)
GND: C1.1, C2.2, C3.2, C4.1, C5.2, C6.1, C7.1, C8.2, C9.2, C10.2, C11.1, C12.2, C13.2, C14.2, C15.2, C16.2, C17.2, C18.1, C19.1, C20.2, C21.2, C22.2, C23.2, C24.2, C25.2, C26.2, C27.2, C28.2, C29.2, C30.2, C31.2, C32.2, C33.2, C38.2, C39.2, C40.2, C41.2, C42.2, D1.1 (K), D2.1 (K), D3.1 (K), D4.1 (K), IC3.1 (S1), IC3.2 (S2), IC3.3 (S3), J1.2, J1.3, J2.09, J2.10, J2.17, J2.18, J2.P01_1 (P01), J2.P01_2 (P01__1), J2.P01_3 (P01__2), J2.P01_4 (P01__3), J2.P01_5 (P01__4), J2.P01_6 (P01__5), J2.P01_7 (P01__6), J2.P01_8 (P01__7), J2.P01_9 (P01__8), J2.P01_10 (P01__9), J2.P02_1 (P02), J2.P02_2 (P02__1), J2.P02_3 (P02__2), J2.P02_4 (P02__3), J2.P02_5 (P02__4), J2.P02_6 (P02__5), J2.P02_7 (P02__6), J2.P02_8 (P02__7), J2.P02_9 (P02__8), J2.P02_10 (P02__9), J2.P03_1 (P03), J2.P03_2 (P03__1), J2.P03_3 (P03__2), J2.P03_4 (P03__3), J2.P03_5 (P03__4), J2.P03_6 (P03__5), J2.P03_7 (P03__6), J2.P03_8 (P03__7), J2.P03_9 (P03__8), J2.P03_10 (P03__9), J2.P04_1 (P04), J2.P04_2 (P04__1), J2.P04_3 (P04__2), J2.P04_4 (P04__3), J2.P04_5 (P04__4), J2.P04_6 (P04__5), J2.P04_7 (P04__6), J2.P04_8 (P04__7), J2.P04_9 (P04__8), J2.P04_10 (P04__9), J2.P07_1 (P07), J2.P07_2 (P07__1), J2.P07_3 (P07__2), J2.P07_4 (P07__3), J2.P07_5 (P07__4), J2.P07_6 (P07__5), J2.P07_7 (P07__6), J2.P07_8 (P07__7), J2.P07_9 (P07__8), J2.P07_10 (P07__9), J2.P08_1 (P08), J2.P08_2 (P08__1), J2.P08_3 (P08__2), J2.P08_4 (P08__3), J2.P08_5 (P08__4), J2.P08_6 (P08__5), J2.P08_7 (P08__6), J2.P08_8 (P08__7), J2.P08_9 (P08__8), J2.P08_10 (P08__9), J3.4, J4.2, J4.3, J6.4, J7.1, J8.03, J9.01, J9.02, J9.03, J9.06, J9.07, J9.08, J9.13, J9.20, J9.24, J9.25, J9.29, J9.30, J13.06, J13.07, J13.08, J13.09, J13.10, J14.06, J14.07, J14.08, J14.09, J14.10, J15.28, J16.1, J17.3, J18.2, J22.3, J23.3, J24.3, J25.3, R2.1, R12.1, R16.2, R19.2, TP5.1, U1.8 (VSSA), U1.23 (VSS), U1.35 (VSS), U1.47 (VSS), U2.2 (GND), U3.1 (*EN2), U3.15 (GND), U3.16 (*EN1), U5.6 (GND), U5.9 (GND), U5.14 (GND), U5.20 (GND), U5.25 (GND), U5.30 (GND), U5.34 (GND), U5.39 (GND), U6.8 (GND), U6.15 (OUTPUTENABLE), U7.8 (GND), U7.15 (OUTPUTENABLE)
unnamed: C36.2, R13.1
unnamed: C37.1, R14.2
unnamed: D1.2 (A), R5.2
unnamed: D2.2 (A), R6.2
unnamed: D3.2 (A), R7.2
unnamed: D4.2 (A), R8.2
unnamed: R19.1, S1.1
unnamed: C31.1, U4.2 (EN/SS)
unnamed: R11.1, U4.3 (PGOOD)
unnamed: U5.S1 (SHIELD), U5.S2 (SHIELD), U5.S3 (SHIELD), U5.S4 (SHIELD)

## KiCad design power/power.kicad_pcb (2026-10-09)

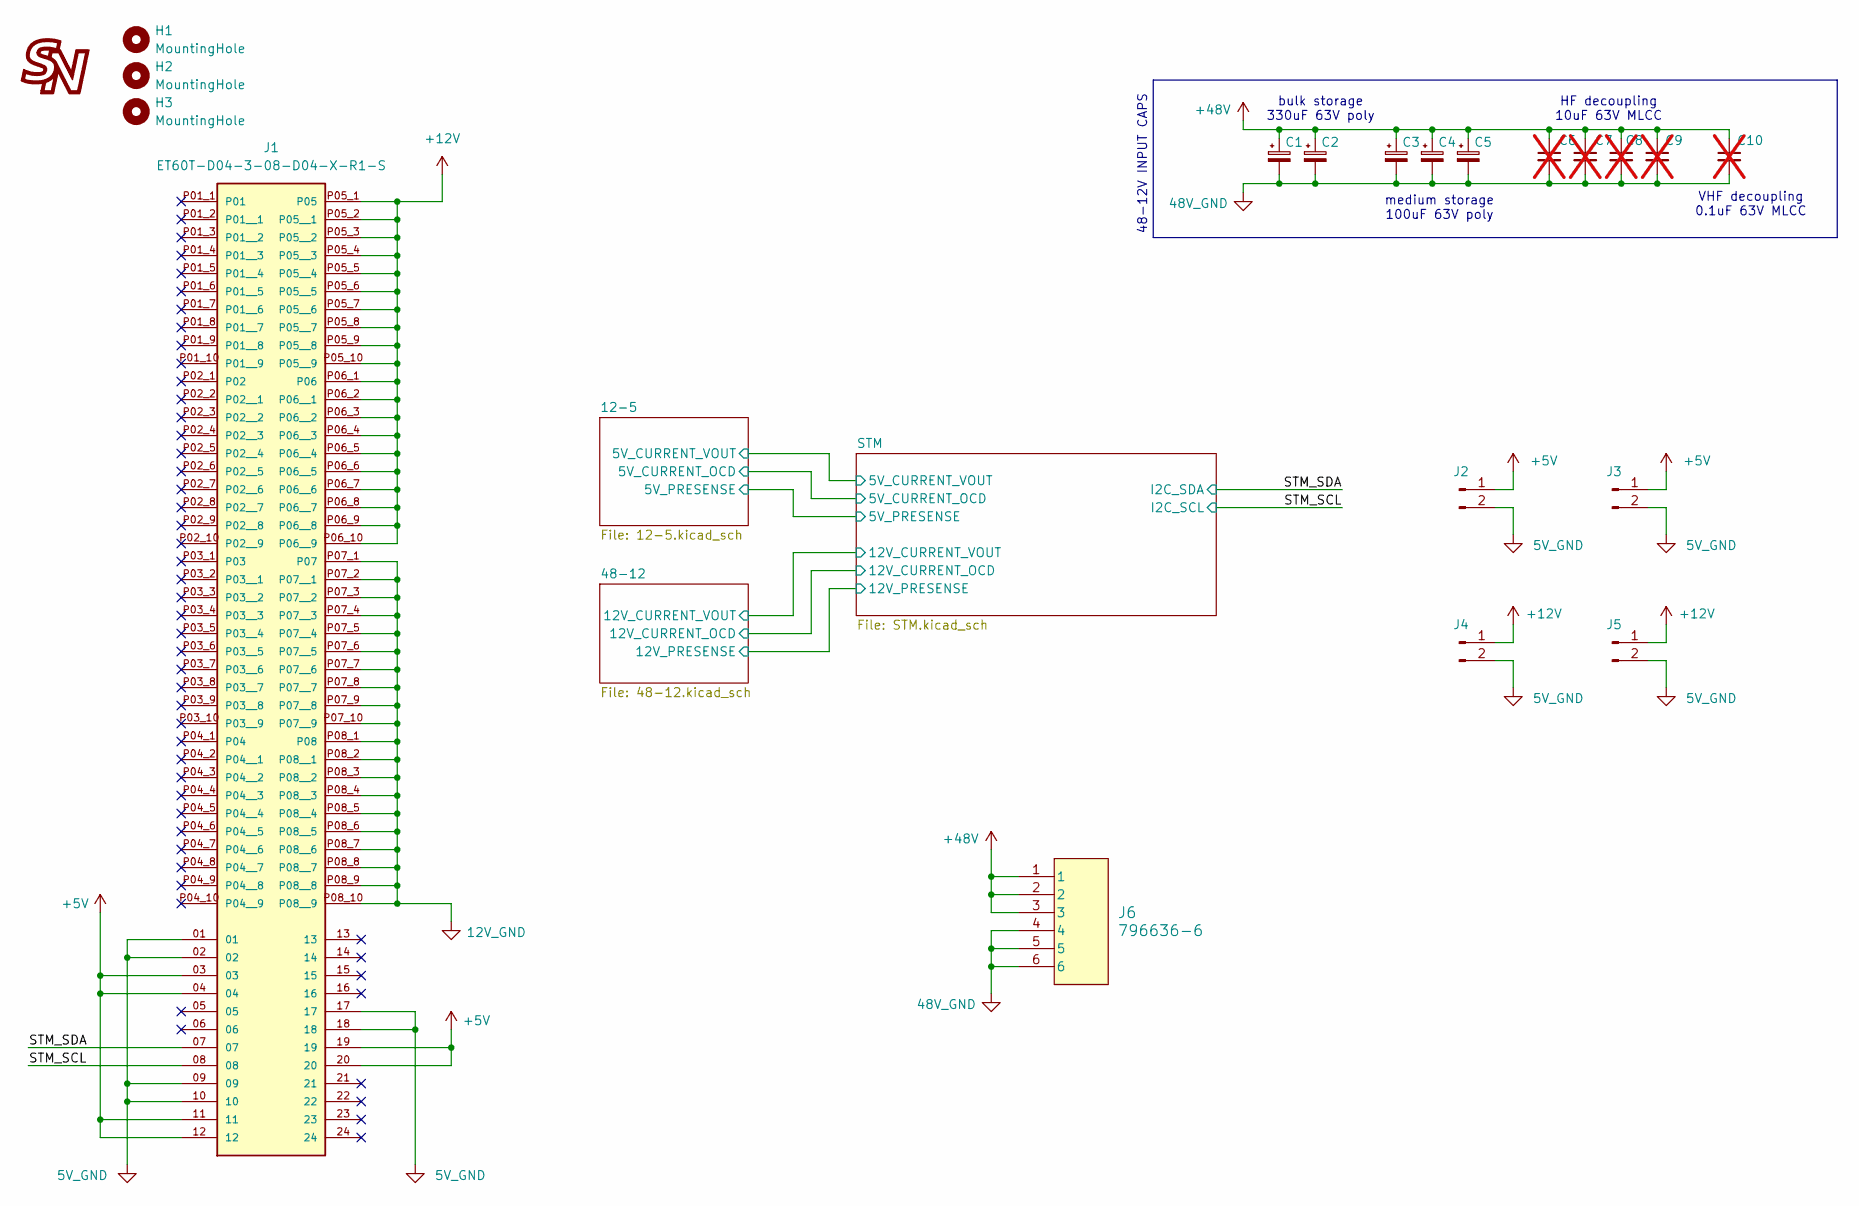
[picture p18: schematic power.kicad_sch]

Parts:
C1, C2: 330uF 63V poly; CP_Radial_D12.5mm_P5.00mm; MPN 63YXJ330M12.5X20; LCSC C437640
C3, C4, C5: 100uF 63V poly; CP_Radial_D8.0mm_P3.50mm; MPN RXW101M1JBK-0815; LCSC C134638
C6, C7, C8, C9: 10uF 63V; C_0603_1608Metric; not fitted
C10: 0.1uF 63V; C_0603_1608Metric; not fitted
G1: LOGO; logo
H1, H2, H3: MountingHole; MountingHole_3.2mm_M3
J1: ET60T-D04-3-08-D04-X-R1-S; SAMTEC_ET60T-D04-3-08-D04-X-R1-S
J2, J3, J4, J5: 2.54mm header; PinHeader_1x02_P2.54mm_Vertical
J6: 796636-6; MPN 796636-6

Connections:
12V_GND: J1.01, J1.02, J1.09, J1.10, J1.17, J1.18, J1.P07_1 (P07), J1.P07_2 (P07__1), J1.P07_3 (P07__2), J1.P07_4 (P07__3), J1.P07_5 (P07__4), J1.P07_6 (P07__5), J1.P07_7 (P07__6), J1.P07_8 (P07__7), J1.P07_9 (P07__8), J1.P07_10 (P07__9), J1.P08_1 (P08), J1.P08_2 (P08__1), J1.P08_3 (P08__2), J1.P08_4 (P08__3), J1.P08_5 (P08__4), J1.P08_6 (P08__5), J1.P08_7 (P08__6), J1.P08_8 (P08__7), J1.P08_9 (P08__8), J1.P08_10 (P08__9), J2.2, J3.2, J4.2, J5.2; also elsewhere on the board
48V_GND: C1.2, C2.2, C3.2, C4.2, C5.2, C6.2, C7.2, C8.2, C9.2, C10.2, J6.4, J6.5, J6.6; also elsewhere on the board
+5V: J1.03, J1.04, J1.11, J1.12, J1.19, J1.20, J2.1, J3.1; also elsewhere on the board
+12V: J1.P05_1 (P05), J1.P05_2 (P05__1), J1.P05_3 (P05__2), J1.P05_4 (P05__3), J1.P05_5 (P05__4), J1.P05_6 (P05__5), J1.P05_7 (P05__6), J1.P05_8 (P05__7), J1.P05_9 (P05__8), J1.P05_10 (P05__9), J1.P06_1 (P06), J1.P06_2 (P06__1), J1.P06_3 (P06__2), J1.P06_4 (P06__3), J1.P06_5 (P06__4), J1.P06_6 (P06__5), J1.P06_7 (P06__6), J1.P06_8 (P06__7), J1.P06_9 (P06__8), J1.P06_10 (P06__9), J4.1, J5.1; also elsewhere on the board
+48V: C1.1, C2.1, C3.1, C4.1, C5.1, C6.1, C7.1, C8.1, C9.1, C10.1, J6.1, J6.2, J6.3; also elsewhere on the board
/STM_SCL: J1.08; also elsewhere on the board
/STM_SDA: J1.07; also elsewhere on the board

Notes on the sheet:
VHF decoupling 0.1uF 63V MLCC
medium storage 100uF 63V poly
HF decoupling 10uF 63V MLCC
bulk storage 330uF 63V poly
48-12V INPUT CAPS

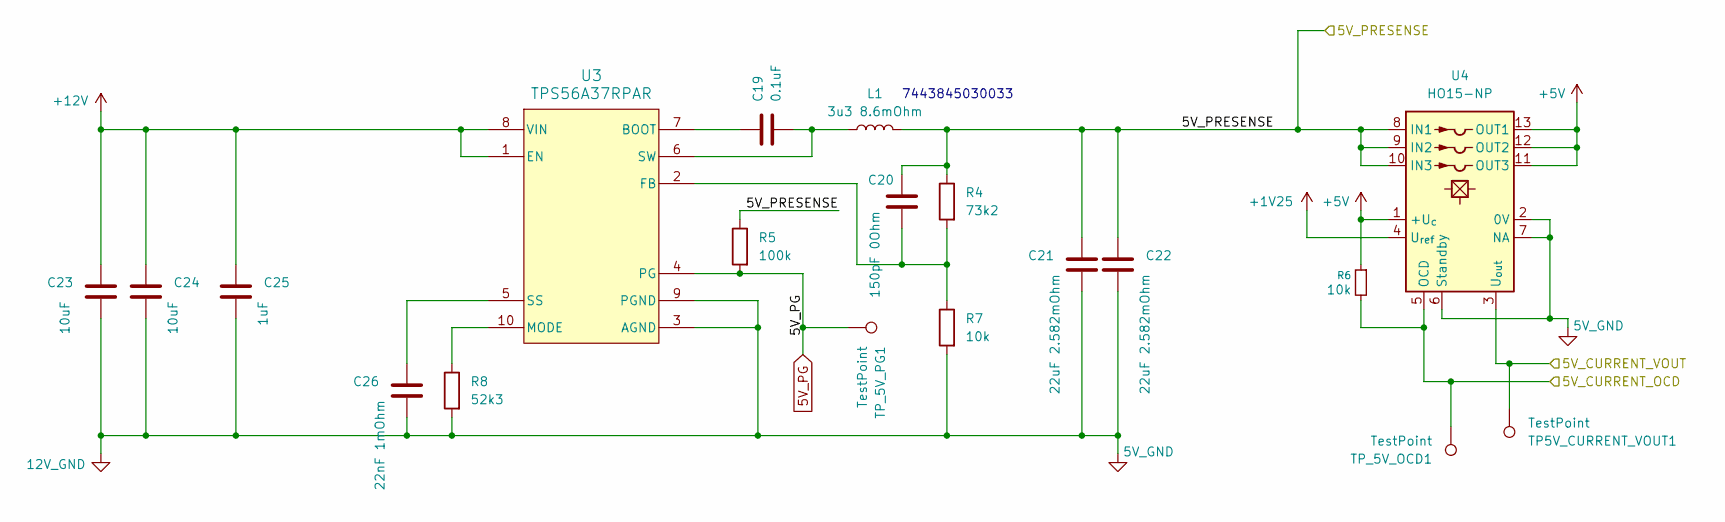
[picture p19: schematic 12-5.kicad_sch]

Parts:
C19: 0.1uF; C_0603_1608Metric; MPN CC0603KRX7R9BB104; LCSC C14663
C20: 150pF 0Ohm; C_0603_1608Metric; MPN CC0603JRNPO9BN151; LCSC C107038
C21, C22: 22uF 2.582mOhm; C_0603_1608Metric; MPN CL10A226MO7JZNC; LCSC C2762594
C23, C24: 10uF; C_0603_1608Metric; MPN CL10A106MA8NRNC; LCSC C96446
C25: 1uF; C_0603_1608Metric; MPN CL10A105KB8NNNC; LCSC C15849
C26: 22nF 1mOhm; C_0603_1608Metric; MPN CC0603KRX7R9BB223; LCSC C106222
L1: 3u3 8.6mOhm; WE-MXGI_5030; MPN 7443845030033
R4: 73k2; R_0603_1608Metric; MPN 0603WAF7322T5E; LCSC C14890
R5: 100k; R_0603_1608Metric; MPN 0603WAF1003T5E; LCSC C25803
R6, R7: 10k; R_0603_1608Metric; MPN 0603WAF1002T5E; LCSC C25804
R8: 52k3; R_0603_1608Metric; MPN 0603WAF5232T5E; LCSC C23198
TP5V_CURRENT_VOUT1: TestPoint; TestPoint_THTPad_2.5x2.5mm_Drill1.2mm
TP_5V_OCD1, TP_5V_PG1: TestPoint; TestPoint_THTPad_2.5x2.5mm_Drill1.2mm
U3: TPS56A37RPAR; MPN TPS56A37RPAR
U4: HO15-NP; LEM_HO8-NP; MPN HO 15-NP-0000

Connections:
5V_PG: R5.2, TP_5V_PG1.1, U3.4 (PG); also elsewhere on the board
12V_GND: C21.2, C22.2, C23.2, C24.2, C25.2, C26.2, R7.2, R8.2, U3.3 (AGND), U3.9 (PGND), U4.2 (0V), U4.6 (Standby), U4.7 (NA); also elsewhere on the board
+1V25: U4.4 (U_{ref}); also elsewhere on the board
+5V: R6.1, U4.1 (+U_{c}), U4.11 (OUT3), U4.12 (OUT2), U4.13 (OUT1); also elsewhere on the board
+12V: C23.1, C24.1, C25.1, U3.1 (EN), U3.8 (VIN); also elsewhere on the board
/12-5/5V_CURRENT_OCD: R6.2, TP_5V_OCD1.1, U4.5 (OCD); also elsewhere on the board
/12-5/5V_CURRENT_VOUT: TP5V_CURRENT_VOUT1.1, U4.3 (U_{out}); also elsewhere on the board
/12-5/5V_PRESENSE: C20.1, C21.1, C22.1, L1.2, R4.1, R5.1, U4.8 (IN1), U4.9 (IN2), U4.10 (IN3); also elsewhere on the board
unnamed: C19.1, U3.7 (BOOT)
unnamed: C20.2, R4.2, R7.1, U3.2 (FB)
unnamed: R8.1, U3.10 (MODE)
unnamed: C26.1, U3.5 (SS)
unnamed: C19.2, L1.1, U3.6 (SW)

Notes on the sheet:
7443845030033

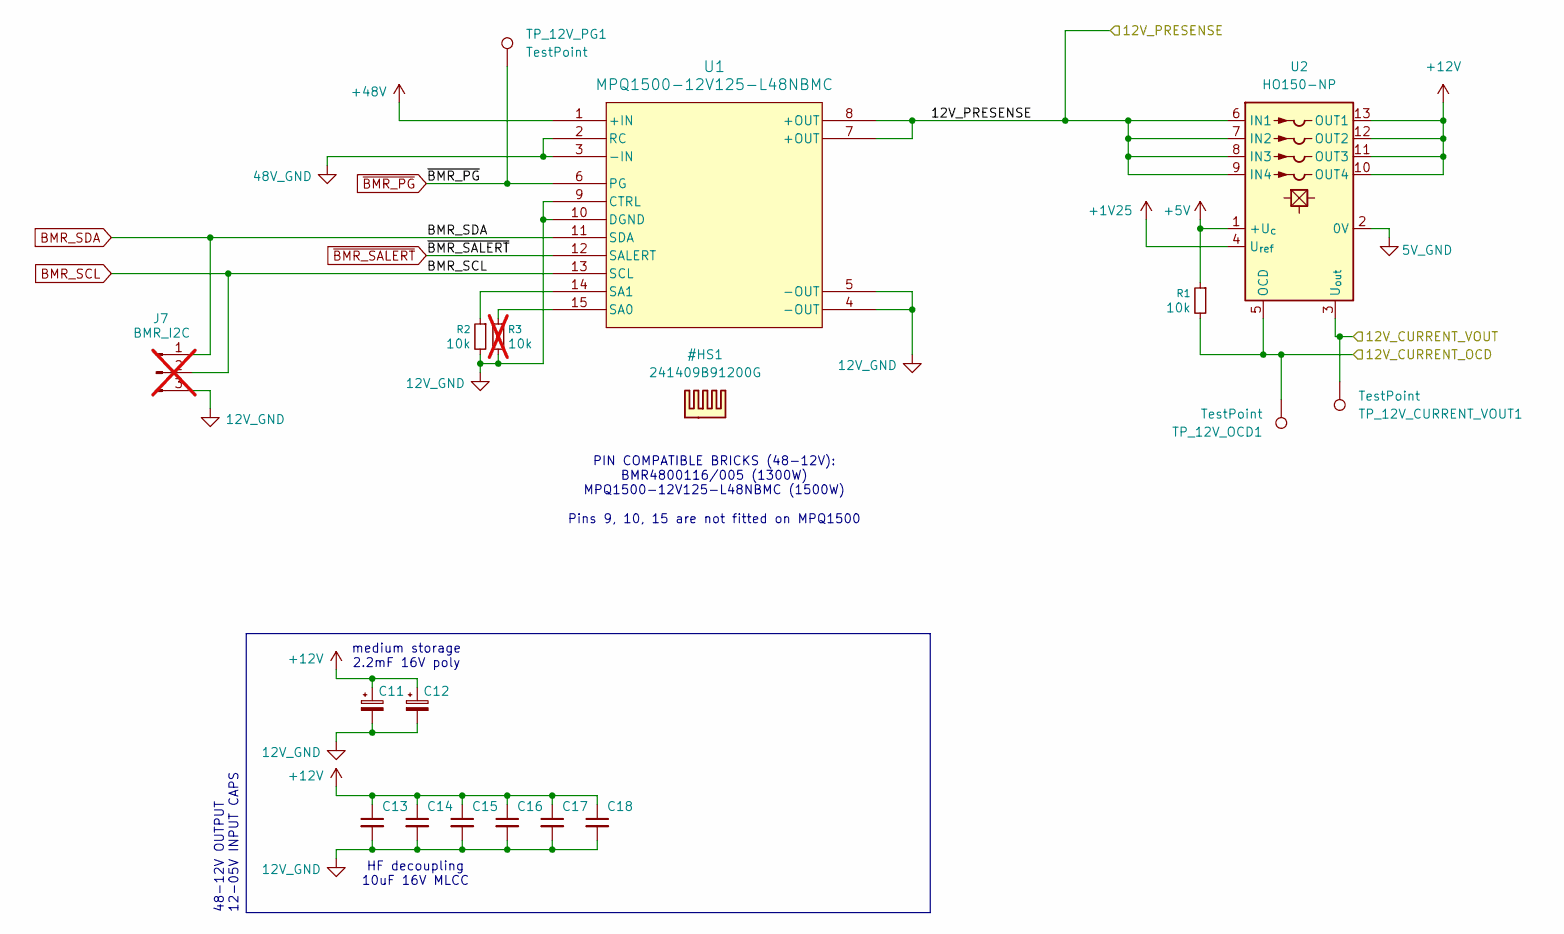
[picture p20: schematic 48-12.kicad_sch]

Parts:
C11, C12: 2.2mF 16V poly; CP_Radial_D18.0mm_P7.50mm; MPN GR1J222MM300A00CV0; LCSC C240374
C13, C14, C15, C16, C17, C18: 10uF; C_0603_1608Metric; MPN CL10A106MA8NRNC; LCSC C96446
J7: BMR_I2C; PinHeader_1x03_P2.54mm_Vertical; not fitted
R1, R2: 10k; R_0603_1608Metric; MPN 0603WAF1002T5E; LCSC C25804
R3: 10k; R_0603_1608Metric; MPN 0603WAF1002T5E; LCSC C25804; not fitted
TP_12V_CURRENT_VOUT1, TP_12V_OCD1, TP_12V_PG1: TestPoint; TestPoint_THTPad_2.5x2.5mm_Drill1.2mm
U1: MPQ1500-12V125-L48NBMC; BMR491_FPM; MPN MPQ1500-12V125-L48NBMC
U2: HO150-NP; LEM_HO150-NP; MPN HO 150-NP-0100

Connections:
12V_GND: C11.2, C12.2, C13.2, C14.2, C15.2, C16.2, C17.2, C18.2, J7.3, R2.2, R3.2, U1.4 (-OUT), U1.5 (-OUT), U1.9 (CTRL), U1.10 (DGND), U2.2 (0V); also elsewhere on the board
48V_GND: U1.2 (RC), U1.3 (-IN); also elsewhere on the board
+1V25: U2.4 (U_{ref}); also elsewhere on the board
+5V: R1.1, U2.1 (+U_{c}); also elsewhere on the board
+12V: C11.1, C12.1, C13.1, C14.1, C15.1, C16.1, C17.1, C18.1, U2.10 (OUT4), U2.11 (OUT3), U2.12 (OUT2), U2.13 (OUT1); also elsewhere on the board
+48V: U1.1 (+IN); also elsewhere on the board
/48-12/12V_CURRENT_OCD: R1.2, TP_12V_OCD1.1, U2.5 (OCD); also elsewhere on the board
/48-12/12V_CURRENT_VOUT: TP_12V_CURRENT_VOUT1.1, U2.3 (U_{out}); also elsewhere on the board
/48-12/12V_PRESENSE: U1.7 (+OUT), U1.8 (+OUT), U2.6 (IN1), U2.7 (IN2), U2.8 (IN3), U2.9 (IN4); also elsewhere on the board
BMR_SCL: J7.2, U1.13 (SCL); also elsewhere on the board
BMR_SDA: J7.1, U1.11 (SDA); also elsewhere on the board
unnamed: R3.1, U1.15 (SA0)
unnamed: R2.1, U1.14 (SA1)
~BMR_PG: TP_12V_PG1.1, U1.6 (PG); also elsewhere on the board
~BMR_SALERT: U1.12 (SALERT); also elsewhere on the board

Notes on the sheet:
HF decoupling 10uF 16V MLCC
PIN COMPATIBLE BRICKS (48-12V): BMR4800116/005 (1300W) MPQ1500-12V125-L48NBMC (1500W) Pins 9, 10, 15 are not fitted on MPQ1500
medium storage 2.2mF 16V poly
48-12V OUTPUT 12-05V INPUT CAPS


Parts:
C27: 0.1uF; C_0603_1608Metric; MPN CC0603KRX7R9BB104; LCSC C14663
C28, C29: 1uF; C_0603_1608Metric; MPN CL10A105KB8NNNC; LCSC C15849
C30, C31, C33, C34: 10uF; C_0603_1608Metric; MPN CL10A106MA8NRNC; LCSC C96446
C32: 3u3; C_0603_1608Metric; MPN TCC0603X5R335M250CT; LCSC C5360803
D1: BLUE; LED_0603_1608Metric; MPN XL-1608UBC-04; LCSC C965807
D2, D5: RED; LED_0603_1608Metric; MPN XL-1608SURC-06; LCSC C965799
D3, D6: GREEN; LED_0603_1608Metric; MPN XL-1608UGC-04; LCSC C965804
D4: PURPLE; LED_0603_1608Metric; MPN XL-1608UVC-04; LCSC C7371898
J8: I2C; PinHeader_1x03_P2.54mm_Vertical
J9: SWD; PinHeader_1x05_P2.54mm_Vertical
R9, R15, R16: 10k; R_0603_1608Metric; MPN 0603WAF1002T5E; LCSC C25804
R10, R11: 10k; R_0603_1608Metric; MPN 0603WAF1002T5E; LCSC C25804; not fitted
R12, R13: 0R; R_0603_1608Metric; MPN 0603WAF0000T5E; LCSC C21189
R14: 30k; R_0603_1608Metric; MPN 0603WAF3002T5E; LCSC C22984
R17: 15k; R_0603_1608Metric; MPN 0603WAF1502T5E; LCSC C22809
R18, R19, R23, R24, R25: 680R 1/4W; R_0603_1608Metric; MPN ERJPA3J681V; LCSC C445820
R20, R21, R22: 120R; R_0603_1608Metric; MPN 0603WAF1200T5E; LCSC C22787
SW1: SW_Push; TS04-66-70-BK-160-SMT; MPN TS04-66-70-BK-160-SMT; LCSC C455109
TP_1V25_1, TP_3V_1, TP_5V_VDETECT1, TP_12V_VDETECT1: TestPoint; TestPoint_THTPad_2.5x2.5mm_Drill1.2mm
U5: TPS7A24125DBVR; SOT-23-5; MPN TPS7A24125DBVR
U6: TPS7A2433DBVR; SOT-23-5; MPN TPS7A2433DBVR
U7: STM32G431KBTx; LQFP-32_7x7mm_P0.8mm; MPN STM32G431KBT6

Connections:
5V_PG: D6.2 (A), U7.27 (PB4); also elsewhere on the board
12V_GND: C27.2, C28.2, C29.2, C30.2, C31.2, C32.2, C33.2, C34.2, D4.1 (K), J8.3, J9.5, R15.2, R17.2, R19.2, R20.2, R22.2, SW1.1, U5.2 (GND), U6.2 (GND), U7.14 (VSSA), U7.16 (VSS), U7.32 (VSS); also elsewhere on the board
48V_GND: R25.2; also elsewhere on the board
+1V25: C30.1, TP_1V25_1.1, U5.5 (V_{OUT}), U7.6 (PA1), U7.12 (PA7); also elsewhere on the board
+3V3: C27.1, C28.1, C29.1, C33.1, D4.2 (A), J9.1, R9.1, R10.1, R11.1, TP_3V_1.1, U6.5 (V_{OUT}), U7.1 (VDD), U7.15 (VDDA), U7.17 (VDD)
+5V: C31.1, C34.1, D3.2 (A), D5.2 (A), U5.1 (V_{IN}), U5.3 (EN), U6.1 (V_{IN}), U6.3 (EN); also elsewhere on the board
+12V: D2.2 (A); also elsewhere on the board
+48V: D1.2 (A); also elsewhere on the board
/12-5/5V_CURRENT_OCD: U7.10 (PA5); also elsewhere on the board
/12-5/5V_CURRENT_VOUT: U7.11 (PA6); also elsewhere on the board
/12-5/5V_PRESENSE: R16.1; also elsewhere on the board
/48-12/12V_CURRENT_OCD: U7.8 (PA3); also elsewhere on the board
/48-12/12V_CURRENT_VOUT: U7.5 (PA0); also elsewhere on the board
/48-12/12V_PRESENSE: R14.1; also elsewhere on the board
/STM/5V_VDETECT: R16.2, R17.1, TP_5V_VDETECT1.1, U7.9 (PA4)
/STM/12V_VDETECT: R14.2, R15.1, TP_12V_VDETECT1.1, U7.7 (PA2)
/STM/SYS_NRST: C32.1, J9.4, R9.2, SW1.2, U7.4 (PG10)
/STM/SYS_SWCLK: J9.3, U7.24 (PA14)
/STM/SYS_SWDIO: J9.2, U7.23 (PA13)
/STM_SCL: J8.2, R11.2, R13.1; also elsewhere on the board
/STM_SDA: J8.1, R10.2, R12.2; also elsewhere on the board
BMR_SCL: U7.31 (PB8); also elsewhere on the board
BMR_SDA: U7.30 (PB7); also elsewhere on the board
unnamed: D1.1 (K), R18.1
unnamed: D2.1 (K), R19.1
unnamed: D3.1 (K), R20.1
unnamed: D5.1 (K), R21.1
unnamed: D6.1 (K), R22.1
unnamed: R18.2, R23.1
unnamed: R23.2, R24.1
unnamed: R24.2, R25.1
unnamed: R12.1, U7.18 (PA8)
unnamed: R13.2, U7.19 (PA9)
~BMR_PG: R21.2, U7.28 (PB5); also elsewhere on the board
~BMR_SALERT: U7.29 (PB6); also elsewhere on the board

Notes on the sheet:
100nF/1uF Decoupling
0-5V mapped to 0-3V
TS04-66-70-BK-160-SMT
0-12V mapped to 0-3V


Board: 2 copper layers, 186.0 x 111.2 mm, 97 parts (0 on the bottom side), 42 nets.

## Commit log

2025-09-20 start of board, footprints etc
    [796636-6.stp, ET60T-D04-3-08-D04-L-R1-S.stp, power.kicad_pcb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]
2025-10-14 added some testpoints and some labeling
    [pi.kicad_sch, power.kicad_sch, sensors.kicad_sch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]
2025-10-18 added leds and minor fixes
    [mcu and pi board.kicad_sch, pi.kicad_sch, power.kicad_sch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]
2025-10-23 minor edits
    [mcu and pi board.kicad_sch, power.kicad_sch, sensors.kicad_sch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]
2025-10-25 pretty much done i think
    [pi.kicad_sch, power.kicad_sch, sensors.kicad_sch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]
2025-11-06 pretty much done
    [mcu and pi board.kicad_sch, pi.kicad_sch, power.kicad_sch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]
2025-11-30 started routing
    [freerouting.dsn, mcu and pi board.kicad_pcb, mcu and pi board.kicad_sch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]
2025-12-06 push before autoroute test, everything done except pi breakout
    [mcu and pi board.kicad_pcb]
2025-12-06 split pi connector
    [mcu and pi board.kicad_pcb, pi.kicad_sch]
2025-12-06 basically done, added a bunch of vias for no reason, for love of the game
    [mcu and pi board.kicad_pcb, pi.kicad_sch]
2025-12-28 basically done
    [mcu and pi board-B_Mask.gbr, mcu and pi board-B_Paste.gbr, mcu and pi board-B_Silkscreen.gbr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]
2025-12-28 added names and pete
    [mcu and pi board.kicad_pcb]
2026-01-05 added vias and some silkscreen art
    [mcu and pi board.kicad_pcb]
2026-01-15 bom updated stuff
    [mcu and pi board.csv, mcu and pi board.kicad_pcb, pi.kicad_sch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]
2026-01-15 commit ig
    [power.kicad_sch]
2026-10-09 sync KiCad library updates and drop stale backups
    [12-5.kicad_sch, 48-12.kicad_sch, 796636-6.stp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]
2026-10-09 clean repo for public portfolio: ignore outputs, drop tracked junk
    - add .gitignore (backups, fab/manufacturing outputs, caches,
    lock files, component source zips, OS junk)
    - untrack 143 generated files (kept on disk); 327 -> 184 tracked
    - write real README (layout, tooling)
    [freerouting.dsn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]
2026-10-09 populate 3D models: fix stale KIPRJMOD paths, add 8 missing STEP refs
    [mcu and pi board.kicad_pcb]
2026-10-09 fix 3D model paths: KIPRJMOD now points at real Libraries dir
    - stale absolute prefix and wrong Libraries base both repaired;
    every local STEP verified present on disk
    - add 8 missing STEP refs (STM32, JST-GH, Molex, CUI jack,
    RPi 4B, XAL6030)
    [mcu and pi board.kicad_pcb]
2026-10-09 lay RPi 4B flat on carrier (rotate model -90 about X)
    [mcu and pi board.kicad_pcb]

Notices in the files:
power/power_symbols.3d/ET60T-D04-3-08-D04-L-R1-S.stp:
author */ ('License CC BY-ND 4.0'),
